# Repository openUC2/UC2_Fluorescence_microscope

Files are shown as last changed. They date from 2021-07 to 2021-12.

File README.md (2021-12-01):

<p align="left">

</p>

# openUC2 Fluorescence Microscope (infinity)
---

This is the repository for the laser-based fluorescence microscope with infinity optics. It is capable to acquire Time-Lapse videos from living cells inside an incubator.

The current version of the Z-stage is inspired by the flexure-bearing Z-stage from Richard Bowman's openflexure microscope design. Their open-source project can be found [here](https://openflexure.org). We also emphasize to use the [delta stage](https://openflexure.org/projects/deltastage/) where [UC2 provides an adapter](https://github.com/openUC2/UC2-GIT/tree/master/CAD/ASSEMBLY_CUBE_Openflexure_Deltastage) for our system.

The setup looks as follows:

<p align="center">
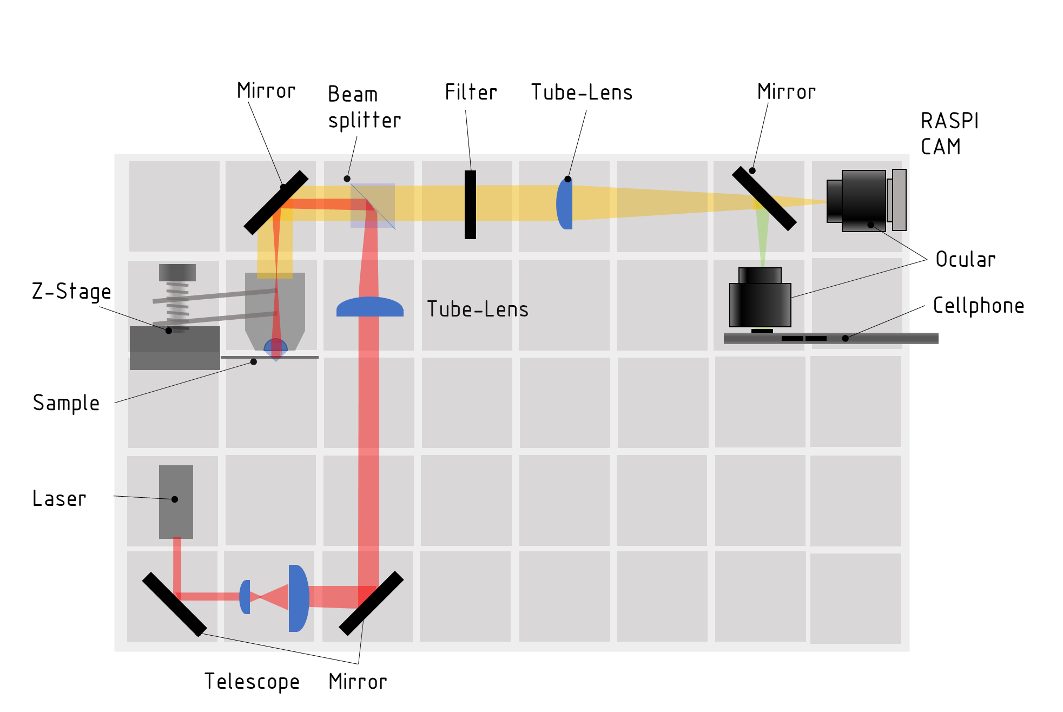
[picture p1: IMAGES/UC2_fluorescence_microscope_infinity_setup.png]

</p>

We use a high power entertainment laser to excite a specific fluorophore, where the emission signal is either filtered by a proper dichroic mirror cube (dichroic+filter) or a low-cost version of a simple 50/50 beamsplitter and an emission filter. The setup uses infinity optics and can either be used with a bare chip or a combination of cellphone camera (with lens) and an eyepiece to achieve proper imaging.

It is a very early developer version. Please feel free to contribute to the documentation and device development.

*Note:* The pictures on this site do not show the latest version of the Z-stage. Follow the respective assembly guidelines.

<p align="center">
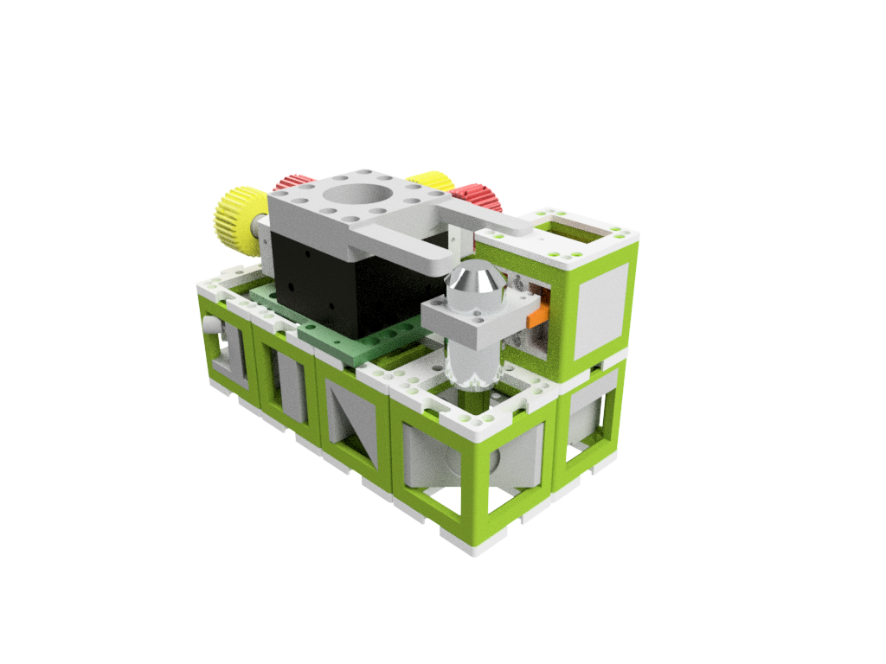
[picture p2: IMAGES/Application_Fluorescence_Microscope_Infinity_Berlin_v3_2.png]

</p>

***Features:***

* X/Y/Z/t Acquisitions possible
* Fluorescent imaging
* Quantitative Phase Imaging
* Modularized design
* Low-cost acquisition
* Based on off-the-shelf components
* Open-Source
* infinity corrected optics
* use of low-cost CMOS sensors possible

# Software
🢂 Find the software for this setup in our dedicated [UC2-Software-GIT](https://github.com/bionanoimaging/UC2-Software-GIT)

# Hardware

Below we describe how the device can be build and assembled in order to replicate the whole system as shown in the rendering above. One needs additional parts that can be found in the core [openUC2 repository](https://github.com/bionanoimaging/UC2-GIT).

### Parts for this setup

<p align="center">
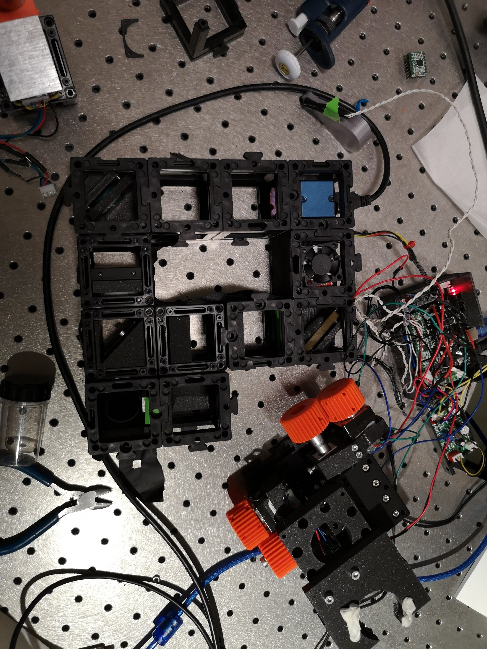
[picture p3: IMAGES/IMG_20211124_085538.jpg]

</p>

| Amount | Type  | Properties | Price | Source |
|----|----|----|----|----|
| 1 | Camera | Daheng Imaging MER2-230-168U3M | 500 € | Daheng Imaging [Link](https://www.machinevisionkamera.de/USB3-Bildverarbeitungskamera-2.3MP-Monochrome-Sony-IMX174-MER2-230-168U3M)|
| 1  | Camera | USB ALVIUM 1800 U -158 | 333 € | Allied Vision [Edmund Optics](https://www.edmundoptics.de/p/allied-vision-alvium-1800-u-158m-129-16mp-s-mount-usb-31-monochrome-camera/42981/) |
| 1 | Laser | 1× Laser Module, 635/637nm entertainment laser (laserlands.net, #3450, Dot Laser Module, 300mW, 50 Euro, China)  | 60 €| [Laserlands.net](https://www.laserlands.net/638nm-laser-500mw-laser-module-red-light-laser.html)|
| 1 | Emission Filter (we used on old Chroma, QE690/55!) | Thorlabs FEL0650 | 78 € | [Thorlabs](https://www.thorlabs.com/thorproduct.cfm?partnumber=FEL0650) |
| 1 | Dichroic Mirror | DMLP650 | 250 € | [Thorlabs](https://www.thorlabs.com/thorproduct.cfm?partnumber=DMLP650) |
| 1 | Shortpass Filter (cleanup)  | FES0650 | 78 € | [Thorlabs](https://www.thorlabs.com/thorproduct.cfm?partnumber=FES0650) |
| 2 | Mirrors 1 inch | Silver, protected mirror | 50 € | [Thorlabs](https://www.thorlabs.com/thorproduct.cfm?partnumber=PF10-03-P01) |
| 1 | Tube lense according to objective lens (imaging-side) | 80 mm for Allied Vision, 150 for Daheng Imaging, Achromat | 96 € | [Thoralbs](https://www.thorlabs.de/thorproduct.cfm?partnumber=AC254-080-A-ML)/[Thoralbs](https://www.thorlabs.de/thorproduct.cfm?partnumber=AC254-150-A-ML) |
| 1 | Tube Lens (illumination-side) | Achromat, f 156,4mm / ∅40,0mm  or  f 150 mm / ∅25,4mm | 5,9 € / 96 € | [PGI-Versand](https://astro-didaktik.de/achromat-2-linser-o-40-mm-f-156-4-mm.html)/[Thoralbs](https://www.thorlabs.de/thorproduct.cfm?partnumber=AC254-150-A-ML) |
| 1 | M3 Screws, DIN ISO 912, various (buy a set) | | ? | Würth |
| 1 | Microscope Objective lens | 1x Objective lens, No Name, 100x, NA1.25, 50 Euro, China | 100 € | [Aliexpress](https://de.aliexpress.com/item/4000200609554.html) |
| 1 | Beam Splitter Dichroic (Discontinued?) | Comar optics Dichro 740 IY als 45° | 40 € | Comar  |
| 1 | Filter Emission (Discontinued?) | Emissionsfilter 655 IY als 0° | 40 € | Comar |
| 200  | Magnets  | 5mm Ball Magnets, NEoxym  | 0,31 | [Magnetmax](https://www.magnetmax.de/Neodym-Kugelmagnete/Magnetkugel-Kugelmagnet-O-5-0-mm-Neodym-vernickelt-N40-haelt-400-g::158.html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) || 4 | Mirrors 1 inch | Thoralbs | ~50 | [Thorlabs](https://www.thorlabs.com/thorproduct.cfm?partnumber=PF10-03-P01) |  1x500 | Screws M3x12 | | ?  | [Würth](https://eshop.wuerth.de/Zylinderschraube-mit-Innensechskant-SHR-ZYL-ISO4762-88-IS25-A2K-M3X12/00843%20%2012.sku/de/DE/EUR/)

Find the complete [Bill-of-Materials here](UC2_Microscope_BillOfMaterial_STORM.xlsx)

## Modules

|  Name | Properties  |  Price | Link  | # |
|---|---|---|---|---|
|  Baseplate puzzle| - | 5€  | [Base-plate](https://github.com/openUC2/UC2-GIT/tree/master/CAD/ASSEMBLY_Baseplate/)  | ~20|
|  Module: Z-Stage | - | ?? €  | [Z-Stage](https://github.com/openUC2/UC2-GIT/tree/master/CAD/ASSEMBLY_CUBE_Z-STAGE_NEMA_MGN)  | 1|
| (Alternative) [Delta stage](https://openflexure.org/projects/deltastage/)  | Openflexure | ?? €  | [Deltastage](https://github.com/openUC2/UC2-GIT/tree/master/CAD/ASSEMBLY_CUBE_Openflexure_Deltastage)  | 1|
|  Module: Kinematic Mirror 45°  (THORLABS!) | - | 5€  | [Kinematic Mirror 45](https://github.com/openUC2/UC2-GIT/tree/master/CAD/ASSEMBLY_CUBE_Mirror_Kinematic_45)  | 2 |
|  Module: Alvium CMOS Camera  | Low-Cost Camera | 5€  | [Alvium Camera](https://github.com/openUC2/UC2-GIT/tree/master/CAD/ASSEMBLY_CUBE_AlliedVision_Alvium)  | 1|
| Alternative (better) Daheng Imaging IMX174 | SMLM Camera | 5€  | [Alvium Camera](https://github.com/openUC2/UC2-GIT/tree/master/CAD/ASSEMBLY_CUBE_AlliedVision_Alvium)  | 1 |
|  Module: Beamsplitter (dichroic)  | - | ??€  | [Dichroic Beam splitter](https://github.com/openUC2/UC2-GIT/tree/master/CAD/ASSEMBLY_CUBE_Dichroic_Beamsplitter)  | 1|
|  Module: Thorlabs + Lens (160mm, 80mm) | - | 5€  | [Thorlabs Insert](https://github.com/openUC2/UC2-GIT/tree/master/CAD/ASSEMBLY_CUBE_Thorlabs)  | 2 |
|  Module: Laser (Block) | - | 5€  | Just mount the laser on the insert using screws. | 2 |
|  Module: 45° Mirror  (Thorlabs) | - | 5€  | [Mirror](https://github.com/openUC2/UC2-GIT/tree/master/CAD/ASSEMBLY_CUBE_Mirror_45)  | 2 |

### Variants

We use various different XY Stages:

[**1. Micrometer XY-stage**](https://github.com/openUC2/UC2-MicronStage)

[**2. Aliexpress Microscop XY-stage**](https://github.com/openUC2/UC2-Motorized-XY-Table)

**3. Openflexure Stage**

### Electronics
🢂 Find more in the [Electronics section](https://github.com/openUC2/UC2-GIT/tree/master/ELECTRONICS)

## Setup variants

**Assembled Setups with a Jetson-driven mono camera:**

For more infos about the camera look [here](https://github.com/openUC2/UC2-GIT/tree/master/CAD/ASSEMBLY_CUBE_AlliedVision_Alvium)

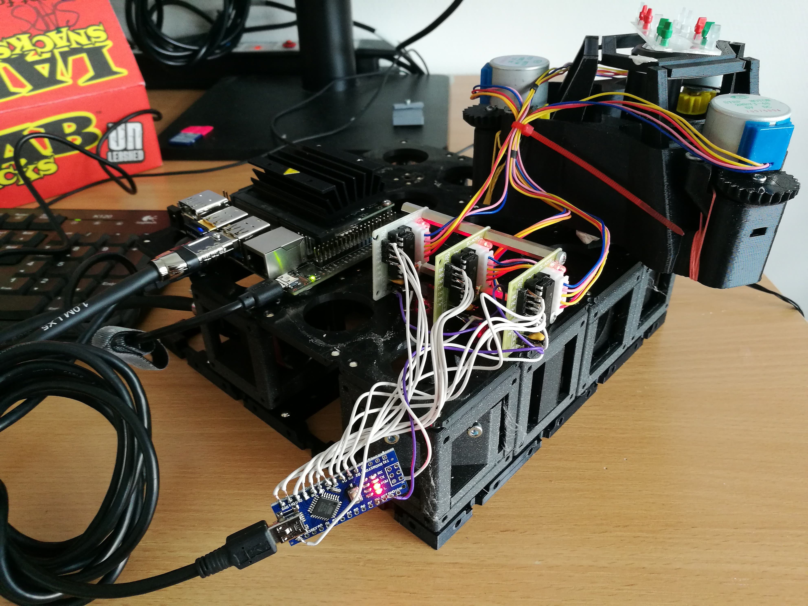
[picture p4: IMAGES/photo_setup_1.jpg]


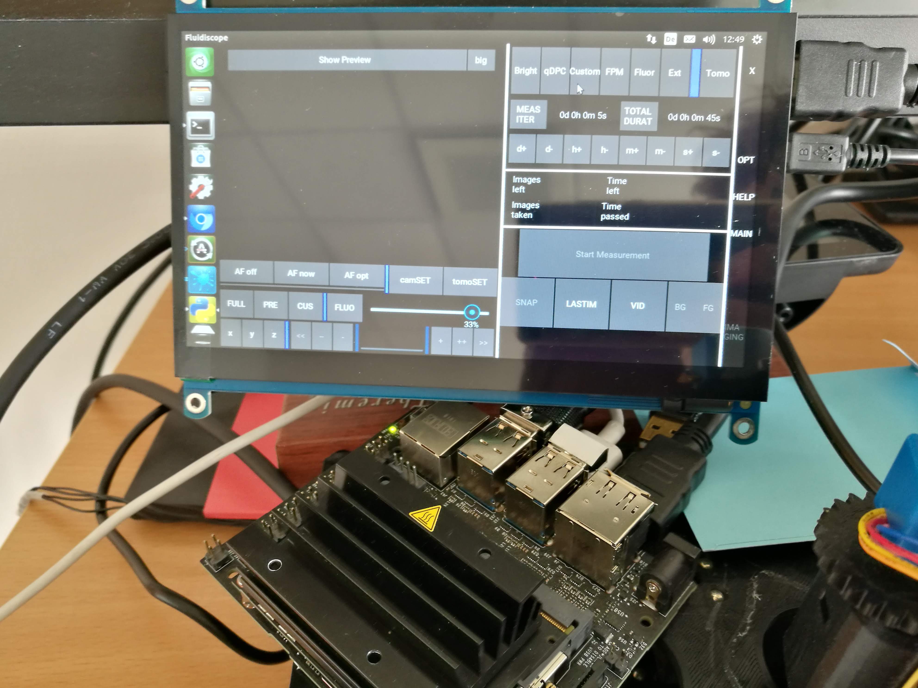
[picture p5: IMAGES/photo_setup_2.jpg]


## Setup

**Side View:**



**Top View:**

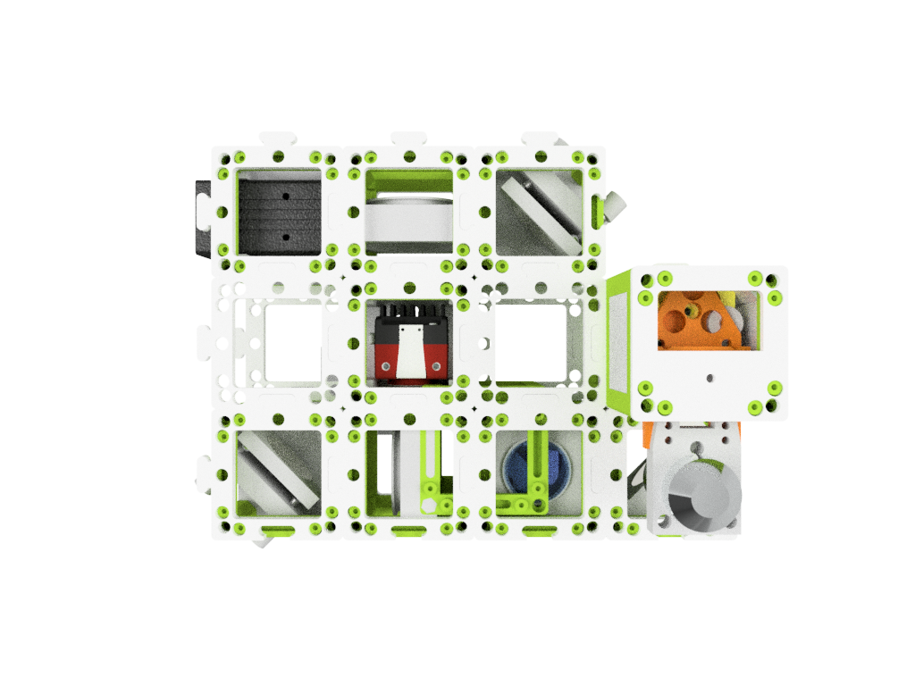
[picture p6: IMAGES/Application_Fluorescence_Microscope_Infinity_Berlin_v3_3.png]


**Backside View:**

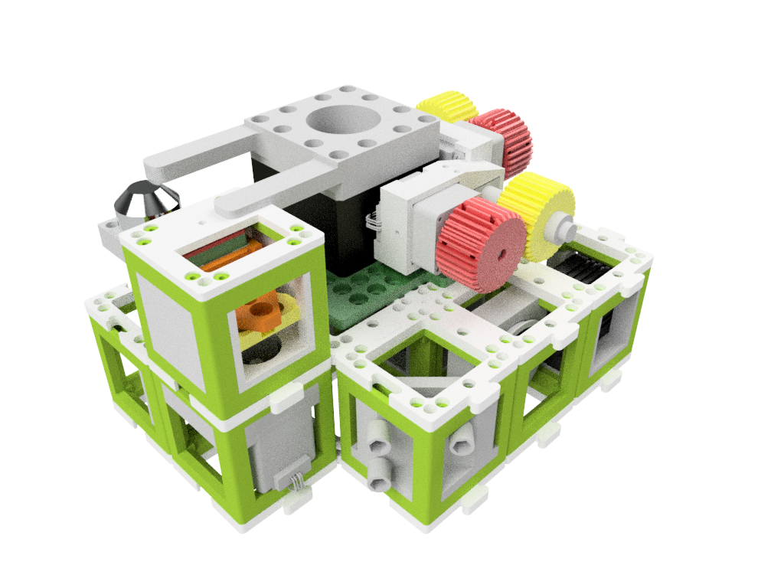
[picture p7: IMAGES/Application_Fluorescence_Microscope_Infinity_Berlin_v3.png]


**Find a little [Tutorial on how to make it work here](Tutorial.md)**

## Showcase
This is a set of ATTO 647 labelled *e.colis* provided by O. Helle from UiO imaged with a 100x, 1.25, a cellphone (Huawei P20 Pro, monochromatic camera, Freedcam) and a 635/637 nm exciation.

<p align="center">
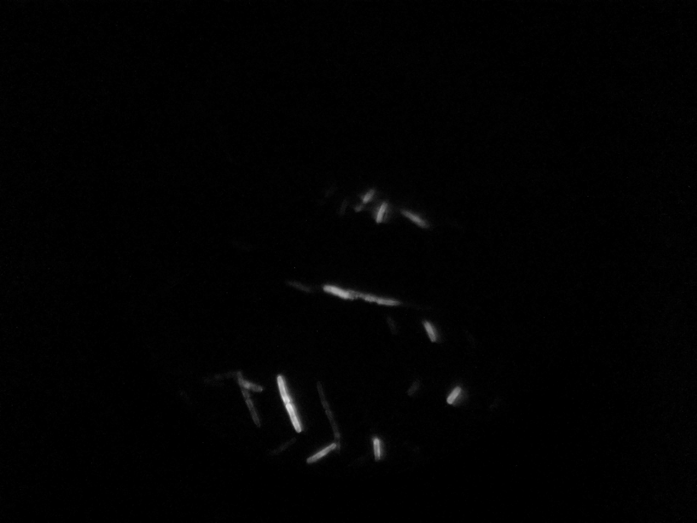
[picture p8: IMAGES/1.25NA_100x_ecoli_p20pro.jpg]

</p>

This is acquired with the Allied Vision Alvium 1500-158 and the new UC2 Nvidia Jetson Nano GUI. HeLa labelled with Alexa Fluor 647 Phal.

***Brightfield***
<p align="center">
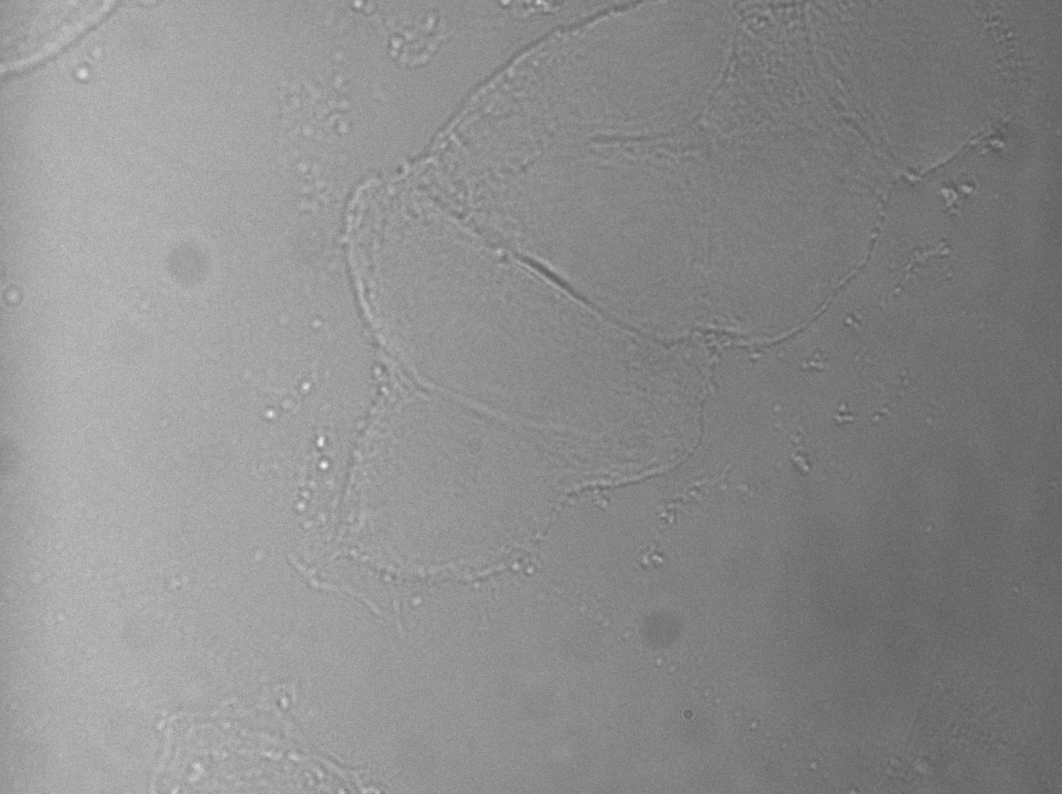
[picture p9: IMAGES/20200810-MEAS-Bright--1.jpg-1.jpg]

</p>

***Fluorescence***
<p align="center">
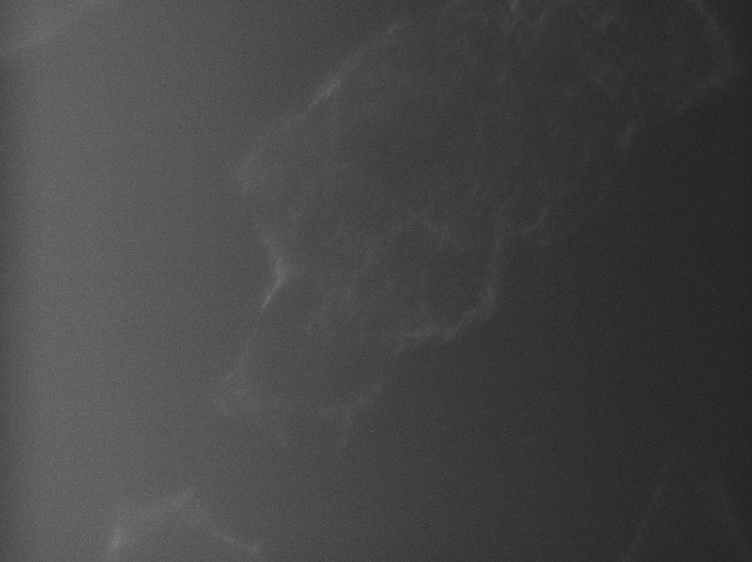
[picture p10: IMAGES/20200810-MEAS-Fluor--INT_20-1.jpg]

</p>

***Overlay***
<p align="center">
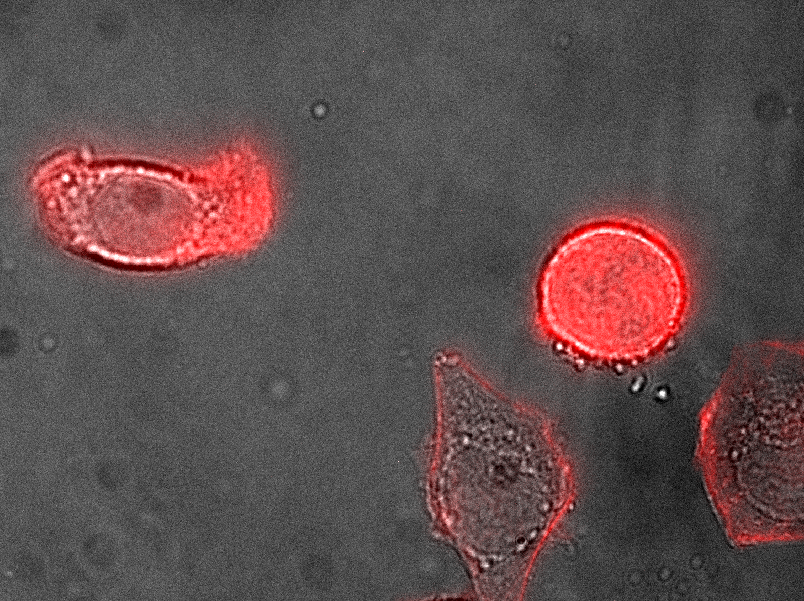
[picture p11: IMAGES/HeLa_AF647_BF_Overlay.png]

</p>

***Optical Setup***
<p align="center">

</p>

***ImSwitch Control Software***
<p align="center">
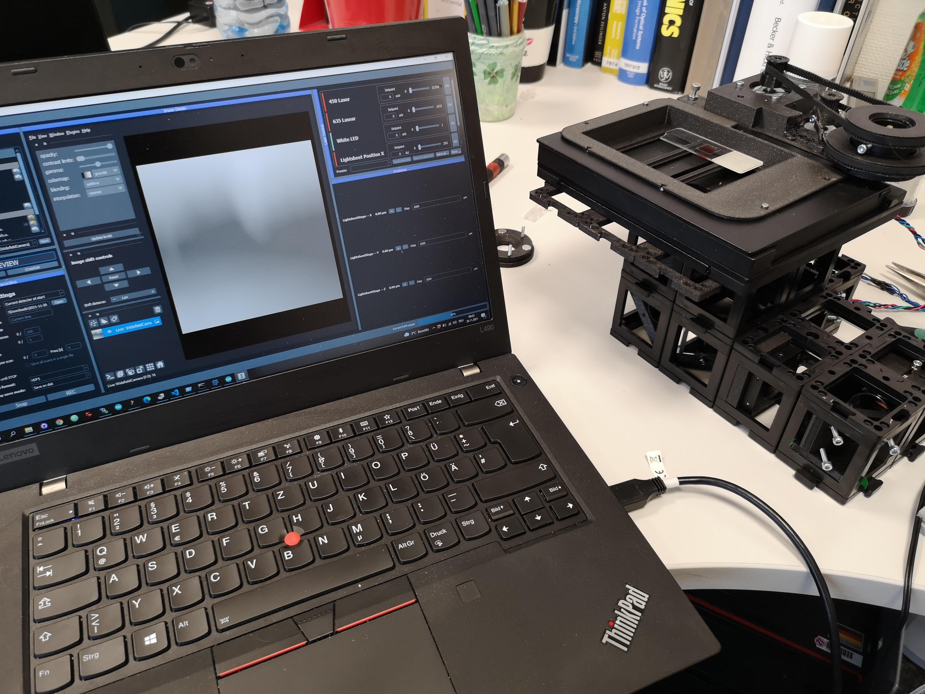
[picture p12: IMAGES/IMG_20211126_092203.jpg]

</p>

***SMLM Sample Holder***
<p align="center">
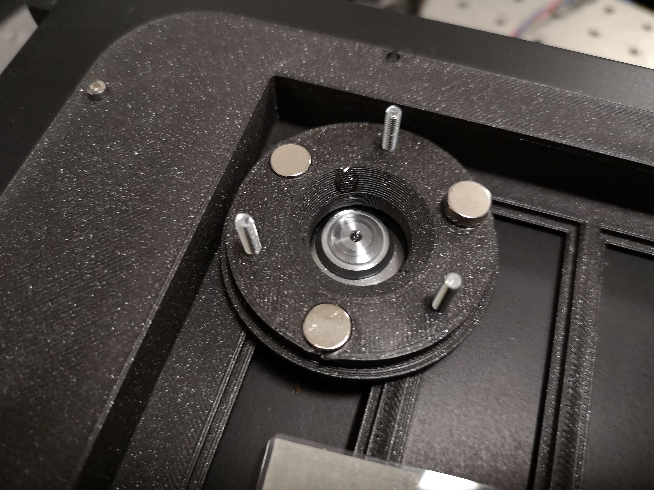
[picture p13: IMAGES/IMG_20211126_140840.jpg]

</p>

## Get Involved

This project is open-source so that anyone can get involved. You don't even have to learn CAD designing or programming. Find ways you can contribute in  [CONTRIBUTING](https://github.com/openUC2/UC2-GIT/blob/master/CONTRIBUTING.md)

## License and Collaboration

This project is open-source and is released under the CERN open hardware license. Our aim is to make the kits commercially available.
We encourage everyone who is using our Toolbox to share their results and ideas, so that the Toolbox keeps improving. It should serve as a easy-to-use and easy-to-access general purpose building block solution for the area of STEAM education. All the design files are generally for free, but we would like to hear from you how is it going.

You're free to fork the project and enhance it. If you have any suggestions to improve it or add any additional functions make a pull-request or file an issue.

Please find the type of licenses [here](https://github.com/openUC2/UC2-GIT/blob/master/License.md)

REMARK: All files have been designed using Autodesk Inventor 2019 (EDUCATION)

## Collaborating
If you find this project useful, please like this repository, follow us on Twitter and cite the webpage! :-)

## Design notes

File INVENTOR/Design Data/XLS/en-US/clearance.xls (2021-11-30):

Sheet: Ansi Unified Screw Threads
I | Sort Order -1
Fastener Type | Size | Shaft Diameters |  |  | Head Dimensions
 |  | Close | Normal | Loose | Diameter | Depth/Angle | Head Type
Flat Head Machine Screw (82) | #0 | 0.0635 | 0.07 | 0.073 | 0.119 | 82 | 2
Flat Head Machine Screw (82) | #1 | 0.076 | 0.081 | 0.089 | 0.146 | 82 | 2
Flat Head Machine Screw (82) | #2 | 0.089 | 0.096 | 0.1065 | 0.172 | 82 | 2
Flat Head Machine Screw (82) | #3 | 0.104 | 0.11 | 0.12 | 0.199 | 82 | 2
Flat Head Machine Screw (82) | #4 | 0.116 | 0.1285 | 0.136 | 0.225 | 82 | 2
Flat Head Machine Screw (82) | #5 | 0.1285 | 0.136 | 0.154 | 0.252 | 82 | 2
Flat Head Machine Screw (82) | #6 | 0.144 | 0.1495 | 0.1695 | 0.279 | 82 | 2
Flat Head Machine Screw (82) | #8 | 0.1695 | 0.177 | 0.1935 | 0.332 | 82 | 2
Flat Head Machine Screw (82) | #10 | 0.196 | 0.201 | 0.221 | 0.385 | 82 | 2
Flat Head Machine Screw (82) | #12 | 0.221 | 0.228 | 0.246 | 0.438 | 82 | 2
Flat Head Machine Screw (82) | 1/4 | 0.257 | 0.266 | 0.2812 | 0.507 | 82 | 2
Flat Head Machine Screw (82) | 5/16 | 0.323 | 0.332 | 0.3437 | 0.635 | 82 | 2
Flat Head Machine Screw (82) | 3/8 | 0.386 | 0.397 | 0.4062 | 0.762 | 82 | 2
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

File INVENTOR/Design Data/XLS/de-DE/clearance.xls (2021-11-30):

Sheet: ANSI UST
I | Reihenfolge -1
Schraubentyp | Größe | Wellendurchmesser |  |  | Schraubenkopfbemaßungen
 |  | Schließen | Normal | Grob | Durchmesser | Tiefe/Winkel | Schraubenkopftyp
Flachkopfmaschinenschraube (82) | #0 | 0.0635 | 0.07 | 0.073 | 0.119 | 82 | 2
Flachkopfmaschinenschraube (82) | #1 | 0.076 | 0.081 | 0.089 | 0.146 | 82 | 2
Flachkopfmaschinenschraube (82) | #2 | 0.089 | 0.096 | 0.1065 | 0.172 | 82 | 2
Flachkopfmaschinenschraube (82) | #3 | 0.104 | 0.11 | 0.12 | 0.199 | 82 | 2
Flachkopfmaschinenschraube (82) | #4 | 0.116 | 0.1285 | 0.136 | 0.225 | 82 | 2
Flachkopfmaschinenschraube (82) | #5 | 0.1285 | 0.136 | 0.154 | 0.252 | 82 | 2
Flachkopfmaschinenschraube (82) | #6 | 0.144 | 0.1495 | 0.1695 | 0.279 | 82 | 2
Flachkopfmaschinenschraube (82) | #8 | 0.1695 | 0.177 | 0.1935 | 0.332 | 82 | 2
Flachkopfmaschinenschraube (82) | #10 | 0.196 | 0.201 | 0.221 | 0.385 | 82 | 2
Flachkopfmaschinenschraube (82) | #12 | 0.221 | 0.228 | 0.246 | 0.438 | 82 | 2
Flachkopfmaschinenschraube (82) | 1/4 | 0.257 | 0.266 | 0.2812 | 0.507 | 82 | 2
Flachkopfmaschinenschraube (82) | 5/16 | 0.323 | 0.332 | 0.3437 | 0.635 | 82 | 2
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

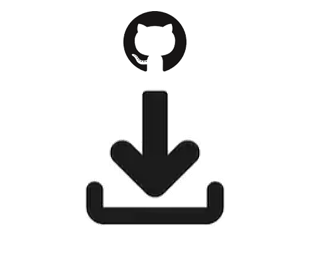
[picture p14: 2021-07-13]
IMAGES/D.png

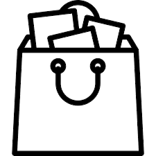
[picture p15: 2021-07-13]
IMAGES/B.png

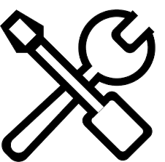
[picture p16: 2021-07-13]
IMAGES/A.png

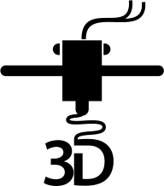
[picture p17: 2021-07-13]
IMAGES/P.png

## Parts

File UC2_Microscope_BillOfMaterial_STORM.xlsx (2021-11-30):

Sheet: NEW
Rough Price for one high-throughput microscope (without Laptop)
Shop | Name | URL | Amount | Price | Final Price
Robotershop | MGN12H Linearlager | https://www.roboter-bausatz.de/p/mgn12h-linearlager | 2 | 10 | 20
 | Linearführung MGN12H 450mm, 50mm (https://www.roboter-bausatz.de/p/linearfuehrung-mgn12h-450mm) | https://www.roboter-bausatz.de/p/mgn12h-linearlager?sPartner=8 | 1 | 30 | 30
 | 1× MKS DLC CNC / Lasergravierer Mainboard GRBL24,95 €* (https://www.roboter-bausatz.de/p/mks-dlc-cnc-lasergravierer-mainboard-grbl) |  | 1 | 12.475 | 12.475
 | 4× A4988 Schrittmotorentreiber5,00 €* (https://www.roboter-bausatz.de/p/a4988-schrittmotorentreiber) |  | 4 | 2.5 | 10
 | 1× yourDroid Netzteil 12V 3A 5,5x2,1mm DC-Stecker9,95 €* (https://www.roboter-bausatz.de/p/yourdroid-netzteil-12v-3a-5-5x2-1mm-dc-stecker) |  | 1 | 4.975 | 4.975
 | 4x jumper kabel 4x |  | 4 | 1 | 4
 | 1× 50 MicroSchalter / Drucktaster 6x6x6mm0,85 €* (https://www.roboter-bausatz.de/p/50-microschalter-drucktaster-6x6x6mm) |  | 1 | 0.425 | 0.425
 | 1× 2 Pin Dupont / Jumper Kabel Buchse-Buchse 70 cm0,45 €* (https://www.roboter-bausatz.de/p/2-pin-dupont-jumper-kabel-buchse-buchse-70-cm) |  | 1 | 0.225 | 0.225
Aliexpress | Twotrees CNC TT-5,5 Laser Gravur Maschine | https://de.aliexpress.com/item/4000033085016.html?spm=a2g0s.9042311.0.0.211d4c4dKo5Nbn | 1 | 129 | 129
Edmund Optics | Allied Vision Alvium USB 3.1 Kamera 1800 U-158m, 1/2,9", 1,58 MP, C-Mount, monochrom (https://www.edmundoptics.de/p/allied-vision-alvium-1800-u-158m-129-158mp-c-mount-usb-31-monochrome-camera/44757/) |  | 1 | 330 | 330
 | 25,4 mm Durchm., Enhanced Aluminium, 4-6 λ Oberflächenspiegel (https://www.edmundoptics.de/p/254mm-dia-enhanced-aluminum-4-6lambda-mirror/26562/) |  | 3 | 21 | 63
 | 6mm Durchmesser x 30mm Länge, M3 Gewinde, Cage-System Stange (https://www.edmundoptics.de/p/6mm-diameter-x-30mm-length-m3-cage-support-rod/28337/) |  | 2 | 11.5 | 23
 | 25,4 mm D. x 88,9 mm Brennweite, VIS 0°-beschichtet, Achromat (https://www.edmundoptics.de/p/254mm-dia-x-889mm-fl-vis-0deg-coated-achromatic-lens/10243/) |  | 1 | 96 | 96
 | 550nm, 25mm Diameter, Dichroic Longpass Filter | https://www.edmundoptics.com/p/550nm-25mm-diameter-dichroic-longpass-filter/24155/ | 0 | 121.125 | 0
 | 500nm, 25mm Diameter, Dichroic Longpass Filter | https://www.edmundoptics.com/p/500nm-25mm-diameter-dichroic-longpass-filter/24154/ | 0 | 121.125 | 0
 | 650nm, 25mm Diameter, Dichroic Longpass Filter | https://www.edmundoptics.com/p/650nm-25mm-diameter-dichroic-longpass-filter/24157/ | 1 | 121.125 | 121.125
 | 500nm, 25mm Dia., OD 2.0 Longpass Filter | https://www.edmundoptics.com/p/500nm-25mm-dia-od-20-longpass-filter/43525/ | 0 | 80.75 | 0
 | 550nm, 25mm Dia., OD 2.0 Longpass Filter | https://www.edmundoptics.com/p/550nm-25mm-dia-od-20-longpass-filter/43526/ | 0 | 80.75 | 0
 | 650nm, 25mm Dia., OD 2.0 Longpass Filter | https://www.edmundoptics.com/p/650nm-25mm-dia-od-20-longpass-filter/43528/ | 1 | 80.75 | 80.75
Optik-Pro | Optika Objektiv IOS LWD W-PLAN POL objective 20x/0.40, M-1138 |  | 0 | 168 | 0
 | Euromex Objektiv IS.7220, 20x/0.40, PLi, plan, infinity (iScope) | https://www.optik-pro.de/fuer-mikroskope/optika-objektiv-ios-lwd-w-plan-pol-objective-20x-0-40-m-1138/p,66005 | 0 | 159 | 0
 | Motic Objektiv CCIS plan achromat. EC-H PL 20x/0.45 (AA=0.9mm) | https://www.optik-pro.de/fuer-mikroskope/euromex-objektiv-is-7220-20x-0-40-pli-plan-infinity-iscope-/p,53372 | 0 | 169 | 0
 | Motic Objektiv EC PL, CCIS, plan, achro, NGC 20x/0.45 w.d. 1mm (BA-310 Elite) | https://www.optik-pro.de/fuer-mikroskope/motic-objektiv-ccis-plan-achromat-ec-h-pl-20x-0-45-aa-0-9mm-/p,45909 | 1 | 113 | 113
 | Windaus Objektiv 10x für HPM 100er Modelle | https://www.optik-pro.de/fuer-mikroskope/motic-objektiv-ec-pl-ccis-plan-achro-ngc-20x-0-45-w-d-1mm-ba-310-elite-/p,57139 | 1 | 32 | 32
 |  | https://www.optik-pro.de/fuer-mikroskope/windaus-objektiv-10x-fuer-hpm-100er-modelle/p,7108 |  |  | 0
 |  |  |  |  | 0
Prusa | Original Prusa Prusament PETG Galaxie Schwarz 1,75 mm 1.000 g |  | 1 | 30 | 30
 |  | https://www.igo3d.com/original-prusa-prusament-petg-filament_8 |  |  | 0
Laserlands.net | 638nm Red Laser Module 500mW Round Dot Focusable TTL 3050 | https://www.laserlands.net/638nm-red-laser-module-500mw-round-dot-focusable-ttl-3050.html | 1 | 25.5 | 25.5
 | 3050-488D-60-12VDC Laserland 488nm Cyan Semiconductor Laser Module 60mW Laser Head Lighting Effect 487nm | https://www.laserlands.net/laserland-488nm-cyan-semiconductor-laser-module-60mw-laser-head-lighting-effect-487nm.html | 0 | 67.1415 | 0
 | 4060 530nm 200mw Green Diode Laser Module | https://www.laserlands.net/11051018.html | 0 | 32.3 | 0
 |  |  |  |  | 0
 |  |  |  |  | 0
Thorlabs | F6SS088- ( Gesamtgewicht):0.01 Kgs, Fine Hex Adjuster, 6-80, 0.88" Long |  | 3 | 7.54 € | 22.62
 | F6SSN1P- ( Gesamtgewicht):0.01 Kgs, Threaded Bushing, Phosphor Bronze, 6-80, 0.25" Long |  | 3 | 4.82 € | 14.46
Misc | Screws |  | 1 | 25 | 25
 | LED (Brightfield) |  | 1 | 20 | 20
UC2 | 45° Mirror |  | 1
 | 45° mirror, kinematic |  | 2
 | Camera |  | 1
 | Filtercube |  | 1
 |  |  | 1
 | Empty |  | 12
 | Cubes total |  | 18 | 15 | 270
 | Baseplates |  | 36 | 10 | 360
 | Working Hours? |  | 8 | 50 | 400
 | Missing Things |  | 1 | 200 | 200
Eckstein | Pololu Stepper Motor NEMA 11 Bipolar 200 Steps Rev 28×32mm 3.8V 0.67 A Phase | https://eckstein-shop.de/PololuStepperMotorNEMA11Bipolar200StepsRev28C39732mm38V067APhase | 1 | 22.95 | 22.95
 |  |  |  | TOTAL: | 2460.505
STORM
Amount | Type | Properties | Price | Source
1 | Camera | Daheng Imaging MER2-230-168U3M | 500 | Daheng Imaging (https://www.alliedvision.com/de/produkte/embedded-vision-kameras/detail/Alvium%201800%20U/-158.html)
1 | Camera | USB ALVIUM 1800 U -158 | 250 | Allied Vision (https://www.alliedvision.com/de/produkte/embedded-vision-kameras/detail/Alvium%201800%20U/-158.html)
1 | Laser | 1× Laser Module, 635/637nm entertainment laser (laserlands.net, #3450, Dot Laser Module, 300mW, 50 Euro, China) (https://www.laserlands.net/diode-laser-module/600nm-640nm-orange-red-laser-module/635dot/200mw-300mw-637nm-638nm-laser-diode-module-ttl-stage-lighting-dj-show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) | 50 | Laserlands.net (https://www.laserlands.net/diode-laser-module/600nm-640nm-orange-red-laser-module/635dot/200mw-300mw-637nm-638nm-laser-diode-module-ttl-stage-lighting-dj-show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)
1 | Beam Splitter Dichroic | Comar optics Dichro 740 IY als 45 | 40 | Comar (https://www.comaroptics.com/components/filters/dichroic-filters/long-pass-dichroic-filters)
1 | Filter Emission | Emissionsfilter 655 IY als 0° | 40 | Comar (https://www.comaroptics.com/components/filters/dichroic-filters/long-pass-dichroic-filters)
1 | Emission Filter | Thorlabs FEL0650 | 78 | Thorlabs
1 | Dichroic Mirror | , DMLP650 | 250 | Thorlabs
1 | Shortpass Filter (cleanup) | FES0650 | 78 | Thorlabs
2 | Mirrors 1 inch | Silver, protected mirror | ~50 | Thorlabs (https://www.thorlabs.com/thorproduct.cfm?partnumber=PF10-03-P01)
1 | Tube lense according to objective lens | 80 mm for Allied Vision, 160 for Daheng Imaging, Achromat | 80 | Thoralbs
1 | Tube Lens | Achromat, f 156,4mm / ∅ 40,0mm | 5.9 | PGI-Versand (https://www.pgi-versand.de/?id=47&mode=artdet&artnr=563.OA.63)
1 | Tube Lens alternative | Achromat, f 182,8mm / ∅ 50,0mm | 7.9 | PGI-Versand (https://www.pgi-versand.de/?id=47&mode=artdet&artnr=564.OA.64)
1 | M3 Screws |  | ? | Würth (https://eshop.wuerth.de/Zylinderschraube-mit-Innensechskant-SHR-ZYL-ISO4762-88-IS25-A2K-M3X12/00843%20%2012.sku/de/DE/EUR/)
1 | Microscope Objective lens | 1x Objective lens, No Name, 100x, NA1.25, 50 Euro, China 🢂 (https://de.aliexpress.com/item/664303199.html) | 100 | https://de.aliexpress.com/item/4000200609554.html

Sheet: OLD
Rough Price for one high-throughput microscope (without Laptop)
Shop | Name | URL | Amount | Price | Final Price
Robotershop | 4× 0,5 Meter Aluprofil 20x20 I-Typ Nut 59,40 €* (https://www.roboter-bausatz.de/p/0-5-meter-aluprofil-20x20-i-typ-nut-5) |  | 4 | 4.7 | 18.8
 | GT2 Riemenscheibe 20 Zähne 5mm Bohrung für 6mm Riemen | https://www.roboter-bausatz.de/p/gt2-riemenscheibe-20-zaehne-5mm-bohrung-fuer-6mm-riemen | 2 | 1.25 | 2.5
 | Nutenstein glatt I-Typ Nut 5 [M4] | https://www.roboter-bausatz.de/p/nutenstein-glatt-i-typ-nut-5-m4 | 10 | 0.6 | 6
 | 2× Wantai Nema 17 Schrittmotor 40mm 1.7A 42BYGHW609X126,90 €* (https://www.roboter-bausatz.de/p/nema-17-schrittmotor-48mm) |  | 2 | 4.7 | 9.4
 | 1× 10 Meter GT2 Zahnriemen offen 6mm10,40 €* (https://www.roboter-bausatz.de/p/10-meter-gt2-zahnriemen-offen-6mm) |  | 1 | 5.2 | 5.2
 | 2× Riemenscheibe GT2 20 Zähne 8mm Bohrung für 6mm Riemen2,90 €* (https://www.roboter-bausatz.de/p/riemenscheibe-gt2-20-zaehne-8mm-bohrung-fuer-6mm-riemen) |  | 2 | 1.45 | 2.9
 | V-Slot Führungsrolle mit Kugellager (klein) | https://www.roboter-bausatz.de/p/v-slot-fuehrungsrolle-mit-kugellager-klein | 6 | 1.25 | 7.5
 | 1× MKS DLC CNC / Lasergravierer Mainboard GRBL24,95 €* (https://www.roboter-bausatz.de/p/mks-dlc-cnc-lasergravierer-mainboard-grbl) |  | 1 | 12.475 | 12.475
 | 4× A4988 Schrittmotorentreiber5,00 €* (https://www.roboter-bausatz.de/p/a4988-schrittmotorentreiber) |  | 4 | 2.5 | 10
 | 1× yourDroid Netzteil 12V 3A 5,5x2,1mm DC-Stecker9,95 €* (https://www.roboter-bausatz.de/p/yourdroid-netzteil-12v-3a-5-5x2-1mm-dc-stecker) |  | 1 | 4.975 | 4.975
 |  |  |  | 0.5 | 0
 | 1× 50 MicroSchalter / Drucktaster 6x6x6mm0,85 €* (https://www.roboter-bausatz.de/p/50-microschalter-drucktaster-6x6x6mm) |  | 1 | 0.425 | 0.425
 | 1× 2 Pin Dupont / Jumper Kabel Buchse-Buchse 70 cm0,45 €* (https://www.roboter-bausatz.de/p/2-pin-dupont-jumper-kabel-buchse-buchse-70-cm) |  | 1 | 0.225 | 0.225
 | 1× 10er Set Befestigungsschrauben Winkel 30 I-Typ DIN 7380 M6x121,86 €* (https://www.roboter-bausatz.de/p/10er-set-befestigungsschrauben-winkel-30-i-typ-din-7380-m6x12) |  | 1 | 0.93 | 0.93
 | MGN12H Linearlager | https://www.roboter-bausatz.de/p/mgn12h-linearlager | 1 | 10 | 10
 | Linearführung MGN12H 450mm, 50mm (https://www.roboter-bausatz.de/p/linearfuehrung-mgn12h-450mm) | https://www.roboter-bausatz.de/p/mgn12h-linearlager?sPartner=8 | 1 | 30 | 30
Edmund Optics | Allied Vision Alvium USB 3.1 Kamera 1800 U-158m, 1/2,9", 1,58 MP, C-Mount, monochrom (https://www.edmundoptics.de/p/allied-vision-alvium-1800-u-158m-129-158mp-c-mount-usb-31-monochrome-camera/44757/) | https://www.roboter-bausatz.de/p/linearfuehrung-mgn12h-450mm | 1 | 330 | 330
 | 25,4 mm Durchm., Enhanced Aluminium, 4-6 λ Oberflächenspiegel (https://www.edmundoptics.de/p/254mm-dia-enhanced-aluminum-4-6lambda-mirror/26562/) |  | 3 | 21 | 63
 | 6mm Durchmesser x 30mm Länge, M3 Gewinde, Cage-System Stange (https://www.edmundoptics.de/p/6mm-diameter-x-30mm-length-m3-cage-support-rod/28337/) |  | 4 | 11.5 | 46
 | 25,4 mm D. x 88,9 mm Brennweite, VIS 0°-beschichtet, Achromat (https://www.edmundoptics.de/p/254mm-dia-x-889mm-fl-vis-0deg-coated-achromatic-lens/10243/) |  | 1 | 96 | 96
 | 550nm, 25mm Diameter, Dichroic Longpass Filter | https://www.edmundoptics.com/p/550nm-25mm-diameter-dichroic-longpass-filter/24155/ | 1 | 121.125 | 121.125
 | 500nm, 25mm Diameter, Dichroic Longpass Filter | https://www.edmundoptics.com/p/500nm-25mm-diameter-dichroic-longpass-filter/24154/ | 1 | 121.125 | 121.125
 | 650nm, 25mm Diameter, Dichroic Longpass Filter | https://www.edmundoptics.com/p/650nm-25mm-diameter-dichroic-longpass-filter/24157/ | 1 | 121.125 | 121.125
 | 500nm, 25mm Dia., OD 2.0 Longpass Filter | https://www.edmundoptics.com/p/500nm-25mm-dia-od-20-longpass-filter/43525/ | 1 | 80.75 | 80.75
 | 550nm, 25mm Dia., OD 2.0 Longpass Filter | https://www.edmundoptics.com/p/550nm-25mm-dia-od-20-longpass-filter/43526/ | 1 | 80.75 | 80.75
 | 650nm, 25mm Dia., OD 2.0 Longpass Filter | https://www.edmundoptics.com/p/650nm-25mm-dia-od-20-longpass-filter/43528/ | 1 | 80.75 | 80.75
Optik-Pro | Optika Objektiv IOS LWD W-PLAN POL objective 20x/0.40, M-1138 |  | 0 | 168 | 0
 | Euromex Objektiv IS.7220, 20x/0.40, PLi, plan, infinity (iScope) | https://www.optik-pro.de/fuer-mikroskope/optika-objektiv-ios-lwd-w-plan-pol-objective-20x-0-40-m-1138/p,66005 | 0 | 159 | 0
 | Motic Objektiv CCIS plan achromat. EC-H PL 20x/0.45 (AA=0.9mm) | https://www.optik-pro.de/fuer-mikroskope/euromex-objektiv-is-7220-20x-0-40-pli-plan-infinity-iscope-/p,53372 | 0 | 169 | 0
 | Motic Objektiv EC PL, CCIS, plan, achro, NGC 20x/0.45 w.d. 1mm (BA-310 Elite) | https://www.optik-pro.de/fuer-mikroskope/motic-objektiv-ccis-plan-achromat-ec-h-pl-20x-0-45-aa-0-9mm-/p,45909 | 1 | 113 | 113
 | Windaus Objektiv 10x für HPM 100er Modelle | https://www.optik-pro.de/fuer-mikroskope/motic-objektiv-ec-pl-ccis-plan-achro-ngc-20x-0-45-w-d-1mm-ba-310-elite-/p,57139 | 1 | 32 | 32
 |  | https://www.optik-pro.de/fuer-mikroskope/windaus-objektiv-10x-fuer-hpm-100er-modelle/p,7108 |  |  | 0
 |  |  |  |  | 0
Prusa | Original Prusa Prusament PETG Galaxie Schwarz 1,75 mm 1.000 g |  | 1 | 30 | 30
 |  | https://www.igo3d.com/original-prusa-prusament-petg-filament_8 |  |  | 0
Laserlands.net | 638nm Red Laser Module 500mW Round Dot Focusable TTL 3050 | https://www.laserlands.net/638nm-red-laser-module-500mw-round-dot-focusable-ttl-3050.html | 1 | 25.5 | 25.5
 | 3050-488D-60-12VDC Laserland 488nm Cyan Semiconductor Laser Module 60mW Laser Head Lighting Effect 487nm | https://www.laserlands.net/laserland-488nm-cyan-semiconductor-laser-module-60mw-laser-head-lighting-effect-487nm.html | 1 | 67.1415 | 67.1415
 | 4060 530nm 200mw Green Diode Laser Module | https://www.laserlands.net/11051018.html | 1 | 32.3 | 32.3
 |  |  |  |  | 0
 |  |  |  |  | 0
Thorlabs | F6SS088- ( Gesamtgewicht):0.01 Kgs, Fine Hex Adjuster, 6-80, 0.88" Long |  | 3 | 7.54 € | 22.62
 | F6SSN1P- ( Gesamtgewicht):0.01 Kgs, Threaded Bushing, Phosphor Bronze, 6-80, 0.25" Long |  | 3 | 4.82 € | 14.46
Misc | Screws |  | 1 | 25 | 25
 | LED (Brightfield) |  | 1 | 20 | 20
UC2 | 45° Mirror |  | 1
 | 45° mirror, kinematic |  | 2
 | Camera |  | 1
 | Filtercube |  | 1
 |  |  | 1
 | Empty |  | 12
 | Cubes total |  | 18 | 15 | 270
 | Baseplates |  | 36 | 10 | 360
 | Working Hours? |  | 10 | 50 | 500
 | Missing Things |  | 1 | 200 | 200
Reichelt
 | MS20 B20X40X50 (https://www.reichelt.de/profil-20-MS20%20B20X40X50) | https://www.reichelt.de/profil-20-offen-b-20-x-40-50-cm-ms20-b20x40x50-p167124.html?&nbc=1 | 1 | 3.7 | 3.7
 | MS20 B20X20X50 | https://www.reichelt.de/profil-20-offen-b-20-x-20-50-cm-ms20-b20x20x50-p167118.html?&nbc=1 | 1 | 7 | 7
 | DEBO JT ESP32 | https://www.reichelt.de/nodemcu-esp32-wifi-und-bluetooth-modul-debo-jt-esp32-p219897.html?&nbc=1 | 2 | 11.5 | 23
Eckstein | Pololu Stepper Motor NEMA 11 Bipolar 200 Steps Rev 28×32mm 3.8V 0.67 A Phase | https://eckstein-shop.de/PololuStepperMotorNEMA11Bipolar200StepsRev28C39732mm38V067APhase | 1 | 22.95 | 22.95
 |  |  |  | TOTAL: | 3030.6265

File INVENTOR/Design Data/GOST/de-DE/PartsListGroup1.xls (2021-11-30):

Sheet: Лист 1
Инв. № подл |  |  |  | Подп. и дата | Взам. инв. № | Инв. № дубл. |  |  | Подп. и дата
Формат | Зона | Поз. | Обозначение |  |  |  | Наименование |  |  |  |  |  | Кол. на исполнение
 |  |  |  |  |  |  |  |  |  |  |  | Лит.
 |  |  |  |  |  |  |  |  |  |  |  | Код
 |  |  |  |  |  |  |  | Изм. | Лист | № докум | Подпись |  | Дата
 |  |  |  |  |  |  |  | Разраб.
 |  |  |  |  |  |  |  | Пров.
 |  |  |  |  |  |  |  | Н.контр
 |  |  |  |  |  |  |  | Утв.
 |  |  |  |  |  |  |  |  |  |  |  |  |  | Копировал

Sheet: Лист 2
Инв. № подл |  |  |  | Подп. и дата | Взам. инв. № | Инв. № дубл. |  |  | Подп. и дата
Формат | Зона | Поз. | Обозначение |  |  |  | Наименование |  |  |  |  | Кол. на исполнение
 |  |  |  |  |  |  |  | Изм. | Лист | № докум. | Подп. | Дата
 |  |  |  |  |  |  |  |  |  |  |  |  | Копировал
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

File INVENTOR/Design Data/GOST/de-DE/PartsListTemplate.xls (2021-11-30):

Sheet: Лист 1
 | Формат | Зона |  | Поз. |  | Обозначение |  |  |  | Наименование |  |  |  | Кол. | Приме-чание
Подп. и дата
Инв. № дубл.
Взам. инв. №
Подп. и дата
 | Изм. |  | Лист |  | № докум |  | Подпись | Дата
Инв. № подл | Разраб. |  |  |  |  |  |  |  |  |  | Литера |  | Лист |  |  | Листов
 | Пров.
 | Н.контр
 | Утв.
 |  |  |  |  |  |  |  |  | Копировал |  |  | Формат А4

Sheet: Лист 2
 | Формат | Зона |  | Поз. |  | Обозначение |  |  |  | Наименование |  | Кол. | Приме-чание
Подп. и дата
Инв. № дубл.
Взам. инв. №
Подп. и дата
Инв. № подл
 | Изм. |  | Лист |  | № докум. |  | Подп. |  | Дата
 |  |  |  |  |  |  |  | Копировал |  |  | Формат А4
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

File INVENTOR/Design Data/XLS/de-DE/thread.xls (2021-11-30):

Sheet: Inch Tapping Threads
I Q X | Zoll-Blechschraubgewinde |  | Sort Order - 5 |  | External |  |  |  |  |  |  | Internal
 |  |  |  |  |  | Major Dia |  | Pitch Dia |  | Minor Dia |  |  | Minor Dia |  | Pitch Dia |  | Major Dia |  | Tap Drill
Size | Size Suffix | Thread Designation | Custom Thread Designation | TPI | Class | Max | Min | Max | Min | Max | Min | Class | Min | Max | Min | Max | Min | Max | Basic
0.0600 |  | 0-48 | 0-48 | 48 | 2B | 0.0600 | 0.0540 | 0.0480 | 0.0435 | 0.0360 | 0.0330
0.0730 |  | 1-42 | 1-42 | 42 | 2B | 0.0750 | 0.0690 | 0.0620 | 0.0575 | 0.0490 | 0.0460
0.0860 |  | 2-32 | 2-32 | 32 | 2B | 0.0880 | 0.0820 | 0.0760 | 0.0710 | 0.0640 | 0.0600
0.0990 |  | 3-28 | 3-28 | 28 | 2B | 0.1010 | 0.0950 | 0.0880 | 0.0830 | 0.0750 | 0.0710
0.1120 |  | 4-24 | 4-24 | 24 | 2B | 0.1140 | 0.1080 | 0.1000 | 0.0950 | 0.0860 | 0.0820
0.1250 |  | 5-20 | 5-20 | 20 | 2B | 0.1300 | 0.1230 | 0.1120 | 0.1065 | 0.0940 | 0.0900
0.1380 |  | 6-20 | 6-20 | 20 | 2B | 0.1390 | 0.1320 | 0.1215 | 0.1155 | 0.1040 | 0.0990
0.1510 |  | 7-19 | 7-19 | 19 | 2B | 0.1540 | 0.1470 | 0.1345 | 0.1280 | 0.1150 | 0.1090
0.1640 |  | 8-18 | 8-18 | 18 | 2B | 0.1660 | 0.1590 | 0.1440 | 0.1375 | 0.1220 | 0.1160
0.1900 |  | 10-16 | 10-16 | 16 | 2B | 0.1890 | 0.1820 | 0.1650 | 0.1585 | 0.1410 | 0.1350
0.2160 |  | 12-14 | 12-14 | 14 | 2B | 0.2150 | 0.2080 | 0.1895 | 0.1825 | 0.1640 | 0.1570
0.2420 |  | 14-14 | 14-14 | 14 | 2B | 0.2410 | 0.2340 | 0.2130 | 0.2060 | 0.1850 | 0.1780
0.2500 |  | 1/4-14 | 1/4-14 | 14 | 2B | 0.2460 | 0.2370 | 0.2190 | 0.2110 | 0.1920 | 0.1850
0.3125 |  | 5/16-12 | 5/16-12 | 12 | 2B | 0.3150 | 0.3060 | 0.2795 | 0.2710 | 0.2440 | 0.2360
0.3750 |  | 3/8-12 | 3/8-12 | 12 | 2B | 0.3800 | 0.3710 | 0.3445 | 0.3350 | 0.3090 | 0.2990
0.4375 |  | 7/16-10 | 7/16-10 | 10 | 2B | 0.4400 | 0.4290 | 0.3995 | 0.3890 | 0.3590 | 0.3490
0.5000 |  | 1/2-10 | 1/2-10 | 10 | 2B | 0.5040 | 0.4930 | 0.4635 | 0.4530 | 0.4230 | 0.4130

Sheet: Metric Forming Screw Threads
M P X | Metrisch geform. Schraubgewinde |  | Sort Order - 6 |  | External |  |  |  |  |  |  | Internal
 |  |  |  |  |  | Major Dia |  | Pitch Dia |  | Minor Dia |  |  | Minor Dia |  | Pitch Dia |  | Major Dia |  | Tap Drill
Size | Size Suffix | Thread Designation | Custom Thread Designation | Pitch | Class | Max | Min | Max | Min | Max | Min | Class | Min | Max | Min | Max | Min | Max | Basic
1.5 |  | 1.5x0.5 | 1.5x0.5 | 0.5 | 6g | 1.520 | 1.380 | 1.215 | 1.110 | 0.910 | 0.840
1.5 |  | ST1.5x0.5 | ST1.5x0.5 | 0.5 | 6g | 1.520 | 1.380 | 1.215 | 1.110 | 0.910 | 0.840
1.9 |  | 1.9x0.6 | 1.9x0.6 | 0.6 | 6g | 1.900 | 1.760 | 1.570 | 1.465 | 1.240 | 1.170
1.9 |  | ST1.9x0.6 | ST1.9x0.6 | 0.6 | 6g | 1.900 | 1.760 | 1.570 | 1.465 | 1.240 | 1.170
2.2 |  | 2.2x0.8 | 2.2x0.8 | 0.8 | 6g | 2.240 | 2.100 | 1.935 | 1.810 | 1.630 | 1.520
2.2 |  | ST2.2x0.8 | ST2.2x0.8 | 0.8 | 6g | 2.240 | 2.100 | 1.935 | 1.810 | 1.630 | 1.520
2.6 |  | 2.6x0.9 | 2.6x0.9 | 0.9 | 6g | 2.570 | 2.430 | 2.235 | 2.115 | 1.900 | 1.800
2.6 |  | ST2.6x0.9 | ST2.6x0.9 | 0.9 | 6g | 2.570 | 2.430 | 2.235 | 2.115 | 1.900 | 1.800
2.9 |  | 2.9x1 | 2.9x1 | 1 | 6g | 2.900 | 2.760 | 2.540 | 2.420 | 2.180 | 2.080
2.9 |  | 2.9x1.1 | 2.9x1.1 | 1.1 | 6g | 2.900 | 2.760 | 2.540 | 2.420 | 2.180 | 2.080
2.9 |  | ST2.9x1.1 | ST2.9x1.1 | 1.1 | 6g | 2.900 | 2.760 | 2.540 | 2.420 | 2.180 | 2.080
2.9 |  | 2.9x1.3 | 2.9x1.3 | 1.3 | 6g | 2.900 | 2.720 | 2.540 | 2.355 | 1.890 | 1.700
2.9 |  | 2.9x1.4 | 2.9x1.4 | 1.4 | 6g | 2.900 | 2.720 | 2.340 | 2.175 | 1.780 | 1.630
3.3 |  | 3.3x1.3 | 3.3x1.3 | 1.3 | 6g | 3.300 | 3.120 | 2.795 | 2.665 | 2.290 | 2.210
3.3 |  | ST3.3x1.3 | ST3.3x1.3 | 1.3 | 6g | 3.300 | 3.120 | 2.795 | 2.665 | 2.290 | 2.210
3.5 |  | 3.5x1.3 | 3.5x1.3 | 1.3 | 6g | 3.530 | 3.350 | 3.085 | 2.930 | 2.640 | 2.510
3.5 |  | ST3.5x1.3 | ST3.5x1.3 | 1.3 | 6g | 3.530 | 3.350 | 3.085 | 2.930 | 2.640 | 2.510
3.5 |  | 3.5x1.6 | 3.5x1.6 | 1.6 | 6g | 3.530 | 3.350 | 2.920 | 2.755 | 2.310 | 2.160
3.5 |  | 3.5x3.2 | 3.5x3.2 | 3.2 | 6g | 3.530 | 3.310 | 2.800 | 2.600 | 2.070 | 1.890
3.9 |  | 3.9x1.3 | 3.9x1.3 | 1.3 | 6g | 3.910 | 3.730 | 3.415 | 3.250 | 2.920 | 2.770
3.9 |  | ST3.9x1.3 | ST3.9x1.3 | 1.3 | 6g | 3.910 | 3.730 | 3.415 | 3.250 | 2.920 | 2.770
3.9 |  | 3.9x1.6 | 3.9x1.6 | 1.6 | 6g | 3.910 | 3.730 | 3.300 | 3.135 | 2.690 | 2.540
3.9 |  | 3.9x3.2 | 3.9x3.2 | 3.2 | 6g | 3.910 | 3.690 | 3.180 | 2.980 | 2.450 | 2.270
4.2 |  | 4.2x1.4 | 4.2x1.4 | 1.4 | 6g | 4.220 | 4.040 | 3.660 | 3.495 | 3.100 | 2.950
4.2 |  | ST4.2x1.4 | ST4.2x1.4 | 1.4 | 6g | 4.220 | 4.040 | 3.660 | 3.495 | 3.100 | 2.950
4.2 |  | 4.2x1.6 | 4.2x1.6 | 1.6 | 6g | 4.220 | 4.040 | 3.610 | 3.445 | 3.000 | 2.850
4.2 |  | 4.2x3.2 | 4.2x3.2 | 3.2 | 6g | 4.220 | 4.000 | 3.380 | 3.180 | 2.540 | 2.360
4.8 |  | 4.8x1.6 | 4.8x1.6 | 1.6 | 6g | 4.800 | 4.620 | 4.190 | 4.025 | 3.580 | 3.430
4.8 |  | ST4.8x1.6 | ST4.8x1.6 | 1.6 | 6g | 4.800 | 4.620 | 4.190 | 4.025 | 3.580 | 3.430
4.8 |  | 4.8x1.8 | 4.8x1.8 | 1.8 | 6g | 4.800 | 4.620 | 4.065 | 3.885 | 3.330 | 3.150
4.8 |  | 4.8x3.2 | 4.8x3.2 | 3.2 | 6g | 4.800 | 4.580 | 3.960 | 3.760 | 3.120 | 2.940
5.5 |  | 5.5x1.8 | 5.5x1.8 | 1.8 | 6g | 5.460 | 5.280 | 4.815 | 4.635 | 4.170 | 3.990
5.5 |  | ST5.5x1.8 | ST5.5x1.8 | 1.8 | 6g | 5.460 | 5.280 | 4.815 | 4.635 | 4.170 | 3.990
6.3 |  | 6.3x1.8 | 6.3x1.8 | 1.8 | 6g | 6.250 | 6.030 | 5.565 | 5.365 | 4.880 | 4.700
6.3 |  | ST6.3x1.8 | ST6.3x1.8 | 1.8 | 6g | 6.250 | 6.030 | 5.565 | 5.365 | 4.880 | 4.700
8.0 |  | 8x2.1 | 8x2.1 | 2.1 | 6g | 8.000 | 7.780 | 7.100 | 6.885 | 6.200 | 5.990
8.0 |  | ST8x2.1 | ST8x2.1 | 2.1 | 6g | 8.000 | 7.780 | 7.100 | 6.885 | 6.200 | 5.990
9.5 |  | 9.5x2.1 | 9.5x2.1 | 2.1 | 6g | 9.650 | 9.430 | 8.750 | 8.510 | 7.850 | 7.590
9.5 |  | ST9.5x2.1 | ST9.5x2.1 | 2.1 | 6g | 9.650 | 9.430 | 8.750 | 8.510 | 7.850 | 7.590

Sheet: ISO Pipe Threads
M Q | ISO-Rohrgewinde |  | Sort Order - 9 |  | External |  |  |  |  |  |  | Internal
 |  |  |  |  |  | Major Dia |  | Pitch Dia |  | Minor Dia |  |  | Minor Dia |  | Pitch Dia |  | Major Dia |  | Tap Drill | Thread Depth | Thread Runouts
Size | Size Suffix | Thread Designation | Custom Thread Designation | TPI | Class | Max | Min | Max | Min | Max | Min | Class | Min | Max | Min | Max | Min | Max | Basic
7.723 |  | G7.723x0.907 | G 1/16 | 28 | A | 7.723 | 7.509 | 7.142 | 7.035 | 6.561 |  |  | 6.561 | 6.834 | 7.142 | 7.249 | 7.723 |  | 1.5875 | 15.446 | 4.5000
7.723 |  | G7.723x0.907 | G 1/16 | 28 | B | 7.723 | 7.509 | 7.142 | 6.928 | 6.561
9.728 |  | G9.728x0.907 | G 1/8 | 28 | A | 9.728 | 9.514 | 9.147 | 9.040 | 8.566 |  |  | 8.566 | 8.848 | 9.147 | 9.254 | 9.728 |  | 3.1750 | 19.456 | 4.5000
9.728 |  | G9.728x0.907 | G 1/8 | 28 | B | 9.728 | 9.514 | 9.147 | 8.933 | 8.566
13.157 |  | G13.157x1.337 | G 1/4 | 19 | A | 13.157 | 12.907 | 12.301 | 12.176 | 11.445 |  |  | 11.445 | 11.89 | 12.301 | 12.426 | 13.157 |  | 6.3500 | 26.314 | 6.5000
13.157 |  | G13.157x1.337 | G 1/4 | 19 | B | 13.157 | 12.907 | 12.301 | 12.051 | 11.445
16.662 |  | G16.662x1.337 | G 3/8 | 19 | A | 16.662 | 16.412 | 15.806 | 15.681 | 14.950 |  |  | 14.95 | 15.395 | 15.806 | 15.931 | 16.662 |  | 9.5250 | 33.324 | 6.5000
16.662 |  | G16.662x1.337 | G 3/8 | 19 | B | 16.662 | 16.412 | 15.806 | 15.556 | 14.950
20.955 |  | G20.955x1.814 | G 1/2 | 14 | A | 20.955 | 20.671 | 19.793 | 19.651 | 18.631 |  |  | 18.631 | 19.172 | 19.793 | 19.935 | 20.955 |  | 12.7000 | 41.910 | 8.5000
20.955 |  | G20.955x1.814 | G 1/2 | 14 | B | 20.955 | 20.671 | 19.793 | 19.509 | 18.631
22.911 |  | G22.911x1.814 | G 5/8 | 14 | A | 22.911 | 22.627 | 21.749 | 21.607 | 20.587 |  |  | 20.587 | 21.128 | 21.749 | 21.891 | 22.911 |  |  | 45.822 | 8.5000
22.911 |  | G22.911x1.814 | G 5/8 | 14 | B | 22.911 | 22.627 | 21.749 | 21.465 | 20.587
26.441 |  | G26.441x1.814 | G 3/4 | 14 | A | 26.441 | 26.157 | 25.279 | 25.137 | 24.117 |  |  | 24.117 | 24.658 | 25.279 | 25.421 | 26.441 |  | 15.8750 | 52.882 | 8.5000
26.441 |  | G26.441x1.814 | G 3/4 | 14 | B | 26.441 | 26.157 | 25.279 | 24.995 | 24.117
30.201 |  | G30.201x1.814 | G 7/8 | 14 | A | 30.201 | 29.917 | 29.039 | 28.897 | 27.877 |  |  | 27.877 | 28.418 | 29.039 | 29.181 | 30.201 |  | 22.2250 | 60.402 | 8.5000
30.201 |  | G30.201x1.814 | G 7/8 | 14 | B | 30.201 | 29.917 | 29.039 | 28.755 | 27.877
33.249 |  | G33.249x2.309 | G 1 | 11 | A | 33.249 | 32.889 | 31.770 | 31.590 | 30.291 |  |  | 30.291 | 30.931 | 31.77 | 31.95 | 33.249 |  | 25.4000 | 66.498 | 10.0000
33.249 |  | G33.249x2.309 | G 1 | 11 | B | 33.249 | 32.889 | 31.770 | 31.410 | 30.291
37.897 |  | G37.897x2.309 | G 1 1/8 | 11 | A | 37.897 | 37.537 | 36.418 | 36.238 | 34.939 |  |  | 34.939 | 35.579 | 36.418 | 36.598 | 37.897 |  | 28.5750 | 75.794 | 10.0000
37.897 |  | G37.897x2.309 | G 1 1/8 | 11 | B | 37.897 | 37.537 | 36.418 | 36.058 | 34.939
41.910 |  | G41.91x2.309 | G 1 1/4 | 11 | A | 41.910 | 41.550 | 40.431 | 40.251 | 38.952 |  |  | 38.952 | 39.592 | 40.431 | 40.611 | 41.910 |  | 31.7500 | 83.820 | 10.0000
41.910 |  | G41.91x2.309 | G 1 1/4 | 11 | B | 41.910 | 41.550 | 40.431 | 40.071 | 38.952
47.803 |  | G47.803x2.309 | G 1 1/2 | 11 | A | 47.803 | 47.443 | 46.324 | 46.144 | 44.845 |  |  | 44.845 | 45.485 | 46.324 | 46.504 | 47.803 |  | 38.1000 | 95.606 | 10.0000
47.803 |  | G47.803x2.309 | G 1 1/2 | 11 | B | 47.803 | 47.443 | 46.324 | 45.964 | 44.845
53.746 |  | G53.746x2.309 | G 1 3/4 | 11 | A | 53.746 | 53.386 | 52.267 | 52.087 | 50.788 |  |  | 50.788 | 51.428 | 52.267 | 52.447 | 53.746 |  | 44.4500 | 107.492 | 10.0000
53.746 |  | G53.746x2.309 | G 1 3/4 | 11 | B | 53.746 | 53.386 | 52.267 | 51.907 | 50.788
59.614 |  | G59.614x2.309 | G 2 | 11 | A | 59.614 | 59.254 | 58.135 | 57.955 | 56.656 |  |  | 56.656 | 57.296 | 58.135 | 58.315 | 59.614 |  | 50.8000 | 119.228 | 10.0000
59.614 |  | G59.614x2.309 | G 2 | 11 | B | 59.614 | 59.254 | 58.135 | 57.775 | 56.656
65.710 |  | G65.71x2.309 | G 2 1/4 | 11 | A | 65.710 | 65.276 | 64.231 | 64.014 | 62.752 |  |  | 62.752 | 63.392 | 64.231 | 64.448 | 65.710 |  | 57.1500 | 131.420 | 10.0000
65.710 |  | G65.71x2.309 | G 2 1/4 | 11 | B | 65.710 | 65.276 | 64.231 | 63.797 | 62.752
75.184 |  | G75.184x2.309 | G 2 1/2 | 11 | A | 75.184 | 74.750 | 73.705 | 73.488 | 72.226 |  |  | 72.226 | 72.866 | 73.705 | 73.922 | 75.184 |  |  | 150.368 | 10.0000
75.184 |  | G75.184x2.309 | G 2 1/2 | 11 | B | 75.184 | 74.750 | 73.705 | 73.271 | 72.226
81.534 |  | G81.534x2.309 | G 2 3/4 | 11 | A | 81.534 | 81.100 | 80.055 | 79.838 | 78.576 |  |  | 78.576 | 79.216 | 80.055 | 80.272 | 81.534 |  | 69.8500 | 163.068 | 10.0000
81.534 |  | G81.534x2.309 | G 2 3/4 | 11 | B | 81.534 | 81.100 | 80.055 | 79.621 | 78.576
87.884 |  | G87.884x2.309 | G 3 | 11 | A | 87.884 | 87.450 | 86.405 | 86.188 | 84.926 |  |  | 84.926 | 85.566 | 86.405 | 86.622 | 87.884 |  | 76.2000 | 175.768 | 10.0000
87.884 |  | G87.884x2.309 | G 3 | 11 | B | 87.884 | 87.450 | 86.405 | 85.971 | 84.926
100.330 |  | G100.33x2.309 | G 3 1/2 | 11 | A | 100.330 | 99.896 | 98.851 | 98.634 | 97.372 |  |  | 97.372 | 98.012 | 98.851 | 99.068 | 100.330 |  | 88.9000 | 200.660 | 10.0000
100.330 |  | G100.33x2.309 | G 3 1/2 | 11 | B | 100.330 | 99.896 | 98.851 | 98.417 | 97.372
113.030 |  | G113.03x2.309 | G 4 | 11 | A | 113.030 | 112.596 | 111.551 | 111.334 | 110.072 |  |  | 110.072 | 110.712 | 111.551 | 111.768 | 113.030 |  | 101.6000 | 226.060 | 10.0000
113.030 |  | G113.03x2.309 | G 4 | 11 | B | 113.030 | 112.596 | 111.551 | 111.117 | 110.072
125.730 |  | G125.73x2.309 | G 4 1/2 | 11 | A | 125.730 | 125.296 | 124.251 | 124.034 | 122.772 |  |  | 122.772 | 123.412 | 124.251 | 124.468 | 125.730 |  | 114.3000 | 251.460 | 10.0000
125.730 |  | G125.73x2.309 | G 4 1/2 | 11 | B | 125.730 | 125.296 | 124.251 | 123.817 | 122.772
138.430 |  | G138.43x2.309 | G 5 | 11 | A | 138.430 | 137.996 | 136.951 | 136.734 | 135.472 |  |  | 135.472 | 136.112 | 136.951 | 137.168 | 138.430 |  | 127.0000 | 276.860 | 10.0000
138.430 |  | G138.43x2.309 | G 5 | 11 | B | 138.430 | 137.996 | 136.951 | 136.517 | 135.472
151.130 |  | G151.13x2.309 | G 5 1/2 | 11 | A | 151.130 | 150.696 | 149.651 | 149.434 | 148.172 |  |  | 148.172 | 148.812 | 149.651 | 149.868 | 151.130 |  | 139.7000 | 302.260 | 10.0000
151.130 |  | G151.13x2.309 | G 5 1/2 | 11 | B | 151.130 | 150.696 | 149.651 | 149.217 | 148.172
163.830 |  | G163.83x2.309 | G 6 | 11 | A | 163.830 | 163.396 | 162.351 | 162.134 | 160.872 |  |  | 160.872 | 161.512 | 162.351 | 162.568 | 163.830 |  | 152.4000 | 327.660 | 10.0000
163.830 |  | G163.83x2.309 | G 6 | 11 | B | 163.830 | 163.396 | 162.351 | 161.917 | 160.872

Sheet: JIS Pipe Threads
M Q | JIS-Rohrgewinde |  | Sort Order -12 |  | External |  |  |  |  |  |  | Internal
 |  |  |  |  |  | Major Dia |  | Pitch Dia |  | Minor Dia |  |  | Minor Dia |  | Pitch Dia |  | Major Dia |  | Tap Drill | Thread Depth | Thread Runouts
Size | Size Suffix | Thread Designation | Custom Thread Designation | TPI | Class | Max | Min | Max | Min | Max | Min | Class | Min | Max | Min | Max | Min | Max | Basic |  | Basic
7.723 |  | G7.723x0.907 | G 1/16 | 28 | A | 7.723 | 7.509 | 7.142 | 7.035 | 6.561 |  |  | 6.561 | 6.834 | 7.142 | 7.249 | 7.723 |  | 1.5875 | 15.446 | 4.5000
7.723 |  | G7.723x0.907 | G 1/16 | 28 | B | 7.723 | 7.509 | 7.142 | 6.928 | 6.561
9.728 |  | G9.728x0.907 | G 1/8 | 28 | A | 9.728 | 9.514 | 9.147 | 9.040 | 8.566 |  |  | 8.566 | 8.848 | 9.147 | 9.254 | 9.728 |  | 3.1750 | 19.456 | 4.5000
9.728 |  | G9.728x0.907 | G 1/8 | 28 | B | 9.728 | 9.514 | 9.147 | 8.933 | 8.566
13.157 |  | G13.157x1.337 | G 1/4 | 19 | A | 13.157 | 12.907 | 12.301 | 12.176 | 11.445 |  |  | 11.445 | 11.89 | 12.301 | 12.426 | 13.157 |  | 6.3500 | 26.314 | 6.5000
13.157 |  | G13.157x1.337 | G 1/4 | 19 | B | 13.157 | 12.907 | 12.301 | 12.051 | 11.445
16.662 |  | G16.662x1.337 | G 3/8 | 19 | A | 16.662 | 16.412 | 15.806 | 15.681 | 14.950 |  |  | 14.95 | 15.395 | 15.806 | 15.931 | 16.662 |  | 9.5250 | 33.324 | 6.5000
16.662 |  | G16.662x1.337 | G 3/8 | 19 | B | 16.662 | 16.412 | 15.806 | 15.556 | 14.950
20.955 |  | G20.955x1.814 | G 1/2 | 14 | A | 20.955 | 20.671 | 19.793 | 19.651 | 18.631 |  |  | 18.631 | 19.172 | 19.793 | 19.935 | 20.955 |  | 12.7000 | 41.910 | 8.5000
20.955 |  | G20.955x1.814 | G 1/2 | 14 | B | 20.955 | 20.671 | 19.793 | 19.509 | 18.631
22.911 |  | G22.911x1.814 | G 5/8 | 14 | A | 22.911 | 22.627 | 21.749 | 21.607 | 20.587 |  |  | 20.587 | 21.128 | 21.749 | 21.891 | 22.911 |  |  | 45.822 | 8.5000
22.911 |  | G22.911x1.814 | G 5/8 | 14 | B | 22.911 | 22.627 | 21.749 | 21.465 | 20.587
26.441 |  | G26.441x1.814 | G 3/4 | 14 | A | 26.441 | 26.157 | 25.279 | 25.137 | 24.117 |  |  | 24.117 | 24.658 | 25.279 | 25.421 | 26.441 |  | 15.8750 | 52.882 | 8.5000
26.441 |  | G26.441x1.814 | G 3/4 | 14 | B | 26.441 | 26.157 | 25.279 | 24.995 | 24.117
30.201 |  | G30.201x1.814 | G 7/8 | 14 | A | 30.201 | 29.917 | 29.039 | 28.897 | 27.877 |  |  | 27.877 | 28.418 | 29.039 | 29.181 | 30.201 |  | 22.2250 | 60.402 | 8.8000
30.201 |  | G30.201x1.814 | G 7/8 | 14 | B | 30.201 | 29.917 | 29.039 | 28.755 | 27.877
33.249 |  | G33.249x2.309 | G 1 | 11 | A | 33.249 | 32.889 | 31.770 | 31.590 | 30.291 |  |  | 30.291 | 30.931 | 31.77 | 31.95 | 33.249 |  | 25.4000 | 66.498 | 10.0000
33.249 |  | G33.249x2.309 | G 1 | 11 | B | 33.249 | 32.889 | 31.770 | 31.410 | 30.291
37.897 |  | G37.897x2.309 | G 1 1/8 | 11 | A | 37.897 | 37.537 | 36.418 | 36.238 | 34.939 |  |  | 34.939 | 35.579 | 36.418 | 36.598 | 37.897 |  | 28.5750 | 75.794 | 10.0000
37.897 |  | G37.897x2.309 | G 1 1/8 | 11 | B | 37.897 | 37.537 | 36.418 | 36.058 | 34.939
41.910 |  | G41.91x2.309 | G 1 1/4 | 11 | A | 41.910 | 41.550 | 40.431 | 40.251 | 38.952 |  |  | 38.952 | 39.592 | 40.431 | 40.611 | 41.910 |  | 31.7500 | 83.820 | 10.0000
41.910 |  | G41.91x2.309 | G 1 1/4 | 11 | B | 41.910 | 41.550 | 40.431 | 40.071 | 38.952
47.803 |  | G47.803x2.309 | G 1 1/2 | 11 | A | 47.803 | 47.443 | 46.324 | 46.144 | 44.845 |  |  | 44.845 | 45.485 | 46.324 | 46.504 | 47.803 |  | 38.1000 | 95.606 | 10.0000
47.803 |  | G47.803x2.309 | G 1 1/2 | 11 | B | 47.803 | 47.443 | 46.324 | 45.964 | 44.845
53.746 |  | G53.746x2.309 | G 1 3/4 | 11 | A | 53.746 | 53.386 | 52.267 | 52.087 | 50.788 |  |  | 50.788 | 51.428 | 52.267 | 52.447 | 53.746 |  | 44.4500 | 107.492 | 10.0000
53.746 |  | G53.746x2.309 | G 1 3/4 | 11 | B | 53.746 | 53.386 | 52.267 | 51.907 | 50.788
59.614 |  | G59.614x2.309 | G 2 | 11 | A | 59.614 | 59.254 | 58.135 | 57.955 | 56.656 |  |  | 56.656 | 57.296 | 58.135 | 58.315 | 59.614 |  | 50.8000 | 119.228 | 10.0000
59.614 |  | G59.614x2.309 | G 2 | 11 | B | 59.614 | 59.254 | 58.135 | 57.775 | 56.656
65.710 |  | G65.71x2.309 | G 2 1/4 | 11 | A | 65.710 | 65.276 | 64.231 | 64.014 | 62.752 |  |  | 62.752 | 63.392 | 64.231 | 64.448 | 65.710 |  | 57.1500 | 131.420 | 10.0000
65.710 |  | G65.71x2.309 | G 2 1/4 | 11 | B | 65.710 | 65.276 | 64.231 | 63.797 | 62.752
75.184 |  | G75.184x2.309 | G 2 1/2 | 11 | A | 75.184 | 74.750 | 73.705 | 73.488 | 72.226 |  |  | 72.226 | 72.866 | 73.705 | 73.922 | 75.184 |  |  | 150.368 | 10.0000
75.184 |  | G75.184x2.309 | G 2 1/2 | 11 | B | 75.184 | 74.750 | 73.705 | 73.271 | 72.226
81.534 |  | G81.534x2.309 | G 2 3/4 | 11 | A | 81.534 | 81.100 | 80.055 | 79.838 | 78.576 |  |  | 78.576 | 79.216 | 80.055 | 80.272 | 81.534 |  | 69.8500 | 163.068 | 10.0000
81.534 |  | G81.534x2.309 | G 2 3/4 | 11 | B | 81.534 | 81.100 | 80.055 | 79.621 | 78.576
87.884 |  | G87.884x2.309 | G 3 | 11 | A | 87.884 | 87.450 | 86.405 | 86.188 | 84.926 |  |  | 84.926 | 85.566 | 86.405 | 86.622 | 87.884 |  | 76.2000 | 175.768 | 10.0000
87.884 |  | G87.884x2.309 | G 3 | 11 | B | 87.884 | 87.450 | 86.405 | 85.971 | 84.926
100.330 |  | G100.33x2.309 | G 3 1/2 | 11 | A | 100.330 | 99.896 | 98.851 | 98.634 | 97.372 |  |  | 97.372 | 98.012 | 98.851 | 99.068 | 100.330 |  | 88.9000 | 200.660 | 10.0000
100.330 |  | G100.33x2.309 | G 3 1/2 | 11 | B | 100.330 | 99.896 | 98.851 | 98.417 | 97.372
113.030 |  | G113.03x2.309 | G 4 | 11 | A | 113.030 | 112.596 | 111.551 | 111.334 | 110.072 |  |  | 110.072 | 110.712 | 111.551 | 111.768 | 113.030 |  | 101.6000 | 226.060 | 10.0000
113.030 |  | G113.03x2.309 | G 4 | 11 | B | 113.030 | 112.596 | 111.551 | 111.117 | 110.072
125.730 |  | G125.73x2.309 | G 4 1/2 | 11 | A | 125.730 | 125.296 | 124.251 | 124.034 | 122.772 |  |  | 122.772 | 123.412 | 124.251 | 124.468 | 125.730 |  | 114.3000 | 251.460 | 10.0000
125.730 |  | G125.73x2.309 | G 4 1/2 | 11 | B | 125.730 | 125.296 | 124.251 | 123.817 | 122.772
138.430 |  | G138.43x2.309 | G 5 | 11 | A | 138.430 | 137.996 | 136.951 | 136.734 | 135.472 |  |  | 135.472 | 136.112 | 136.951 | 137.168 | 138.430 |  | 127.0000 | 276.860 | 10.0000
138.430 |  | G138.43x2.309 | G 5 | 11 | B | 138.430 | 137.996 | 136.951 | 136.517 | 135.472
151.130 |  | G151.13x2.309 | G 5 1/2 | 11 | A | 151.130 | 150.696 | 149.651 | 149.434 | 148.172 |  |  | 148.172 | 148.812 | 149.651 | 149.868 | 151.130 |  | 139.7000 | 302.260 | 10.0000
151.130 |  | G151.13x2.309 | G 5 1/2 | 11 | B | 151.130 | 150.696 | 149.651 | 149.217 | 148.172
163.830 |  | G163.83x2.309 | G 6 | 11 | A | 163.830 | 163.396 | 162.351 | 162.134 | 160.872 |  |  | 160.872 | 161.512 | 162.351 | 162.568 | 163.830 |  | 152.4000 | 327.660 | 10.0000
163.830 |  | G163.83x2.309 | G 6 | 11 | B | 163.830 | 163.396 | 162.351 | 161.917 | 160.872

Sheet: DIN Pipe Threads
M Q | DIN-Rohrgewinde |  | Sort Order - 18 |  | External |  |  |  |  |  |  | Internal
 |  |  |  |  |  | Major Dia |  | Pitch Dia |  | Minor Dia |  |  | Minor Dia |  | Pitch Dia |  | Major Dia |  | Tap Drill | Thread Depth | Thread Runouts
Size | Size Suffix | Thread Designation | Custom Thread Designation | TPI | Class | Max | Min | Max | Min | Max | Min | Class | Min | Max | Min | Max | Min | Max | Basic
7.723 |  | G7.723x0.907 | G 1/16 | 28 | A | 7.723 | 7.509 | 7.142 | 7.035 | 6.561 |  |  | 6.561 | 6.834 | 7.142 | 7.249 | 7.723 |  | 1.5875 | 15.446 | 4.5000
7.723 |  | G7.723x0.907 | G 1/16 | 28 | B | 7.723 | 7.509 | 7.142 | 6.928 | 6.561
9.728 |  | G9.728x0.907 | G 1/8 | 28 | A | 9.728 | 9.514 | 9.147 | 9.040 | 8.566 |  |  | 8.566 | 8.848 | 9.147 | 9.254 | 9.728 |  | 3.1750 | 19.456 | 4.5000
9.728 |  | G9.728x0.907 | G 1/8 | 28 | B | 9.728 | 9.514 | 9.147 | 8.933 | 8.566
13.157 |  | G13.157x1.337 | G 1/4 | 19 | A | 13.157 | 12.907 | 12.301 | 12.176 | 11.445 |  |  | 11.445 | 11.89 | 12.301 | 12.426 | 13.157 |  | 6.3500 | 26.314 | 6.5000
13.157 |  | G13.157x1.337 | G 1/4 | 19 | B | 13.157 | 12.907 | 12.301 | 12.051 | 11.445
16.662 |  | G16.662x1.337 | G 3/8 | 19 | A | 16.662 | 16.412 | 15.806 | 15.681 | 14.950 |  |  | 14.95 | 15.395 | 15.806 | 15.931 | 16.662 |  | 9.5250 | 33.324 | 6.5000
16.662 |  | G16.662x1.337 | G 3/8 | 19 | B | 16.662 | 16.412 | 15.806 | 15.556 | 14.950
20.955 |  | G20.955x1.814 | G 1/2 | 14 | A | 20.955 | 20.671 | 19.793 | 19.651 | 18.631 |  |  | 18.631 | 19.172 | 19.793 | 19.935 | 20.955 |  | 12.7000 | 41.910 | 8.5000
20.955 |  | G20.955x1.814 | G 1/2 | 14 | B | 20.955 | 20.671 | 19.793 | 19.509 | 18.631
22.911 |  | G22.911x1.814 | G 5/8 | 14 | A | 22.911 | 22.627 | 21.749 | 21.607 | 20.587 |  |  | 20.587 | 21.128 | 21.749 | 21.891 | 22.911 |  |  | 45.822 | 8.5000
22.911 |  | G22.911x1.814 | G 5/8 | 14 | B | 22.911 | 22.627 | 21.749 | 21.465 | 20.587
26.441 |  | G26.441x1.814 | G 3/4 | 14 | A | 26.441 | 26.157 | 25.279 | 25.137 | 24.117 |  |  | 24.117 | 24.658 | 25.279 | 25.421 | 26.441 |  | 15.8750 | 52.882 | 8.5000
26.441 |  | G26.441x1.814 | G 3/4 | 14 | B | 26.441 | 26.157 | 25.279 | 24.995 | 24.117
30.201 |  | G30.201x1.814 | G 7/8 | 14 | A | 30.201 | 29.917 | 29.039 | 28.897 | 27.877 |  |  | 27.877 | 28.418 | 29.039 | 29.181 | 30.201 |  | 22.2250 | 60.402 | 8.5000
30.201 |  | G30.201x1.814 | G 7/8 | 14 | B | 30.201 | 29.917 | 29.039 | 28.755 | 27.877
33.249 |  | G33.249x2.309 | G 1 | 11 | A | 33.249 | 32.889 | 31.770 | 31.590 | 30.291 |  |  | 30.291 | 30.931 | 31.77 | 31.95 | 33.249 |  | 25.4000 | 66.498 | 10.5000
33.249 |  | G33.249x2.309 | G 1 | 11 | B | 33.249 | 32.889 | 31.770 | 31.410 | 30.291
37.897 |  | G37.897x2.309 | G 1 1/8 | 11 | A | 37.897 | 37.537 | 36.418 | 36.238 | 34.939 |  |  | 34.939 | 35.579 | 36.418 | 36.598 | 37.897 |  | 28.5750 | 75.794 | 10.5000
37.897 |  | G37.897x2.309 | G 1 1/8 | 11 | B | 37.897 | 37.537 | 36.418 | 36.058 | 34.939
41.910 |  | G41.91x2.309 | G 1 1/4 | 11 | A | 41.910 | 41.550 | 40.431 | 40.251 | 38.952 |  |  | 38.952 | 39.592 | 40.431 | 40.611 | 41.910 |  | 31.7500 | 83.820 | 10.5000
41.910 |  | G41.91x2.309 | G 1 1/4 | 11 | B | 41.910 | 41.550 | 40.431 | 40.071 | 38.952
47.803 |  | G47.803x2.309 | G 1 1/2 | 11 | A | 47.803 | 47.443 | 46.324 | 46.144 | 44.845 |  |  | 44.845 | 45.485 | 46.324 | 46.504 | 47.803 |  | 38.1000 | 95.606 | 10.5000
47.803 |  | G47.803x2.309 | G 1 1/2 | 11 | B | 47.803 | 47.443 | 46.324 | 45.964 | 44.845
53.746 |  | G53.746x2.309 | G 1 3/4 | 11 | A | 53.746 | 53.386 | 52.267 | 52.087 | 50.788 |  |  | 50.788 | 51.428 | 52.267 | 52.447 | 53.746 |  | 44.4500 | 107.492 | 10.5000
53.746 |  | G53.746x2.309 | G 1 3/4 | 11 | B | 53.746 | 53.386 | 52.267 | 51.907 | 50.788
59.614 |  | G59.614x2.309 | G 2 | 11 | A | 59.614 | 59.254 | 58.135 | 57.955 | 56.656 |  |  | 56.656 | 57.296 | 58.135 | 58.315 | 59.614 |  | 50.8000 | 119.228 | 10.5000
59.614 |  | G59.614x2.309 | G 2 | 11 | B | 59.614 | 59.254 | 58.135 | 57.775 | 56.656
65.710 |  | G65.71x2.309 | G 2 1/4 | 11 | A | 65.710 | 65.276 | 64.231 | 64.014 | 62.752 |  |  | 62.752 | 63.392 | 64.231 | 64.448 | 65.710 |  | 57.1500 | 131.420 | 10.5000
65.710 |  | G65.71x2.309 | G 2 1/4 | 11 | B | 65.710 | 65.276 | 64.231 | 63.797 | 62.752
75.184 |  | G75.184x2.309 | G 2 1/2 | 11 | A | 75.184 | 74.750 | 73.705 | 73.488 | 72.226 |  |  | 72.226 | 72.866 | 73.705 | 73.922 | 75.184 |  |  | 150.368 | 10.5000
75.184 |  | G75.184x2.309 | G 2 1/2 | 11 | B | 75.184 | 74.750 | 73.705 | 73.271 | 72.226
81.534 |  | G81.534x2.309 | G 2 3/4 | 11 | A | 81.534 | 81.100 | 80.055 | 79.838 | 78.576 |  |  | 78.576 | 79.216 | 80.055 | 80.272 | 81.534 |  | 69.8500 | 163.068 | 10.5000
81.534 |  | G81.534x2.309 | G 2 3/4 | 11 | B | 81.534 | 81.100 | 80.055 | 79.621 | 78.576
87.884 |  | G87.884x2.309 | G 3 | 11 | A | 87.884 | 87.450 | 86.405 | 86.188 | 84.926 |  |  | 84.926 | 85.566 | 86.405 | 86.622 | 87.884 |  | 76.2000 | 175.768 | 10.5000
87.884 |  | G87.884x2.309 | G 3 | 11 | B | 87.884 | 87.450 | 86.405 | 85.971 | 84.926
100.330 |  | G100.33x2.309 | G 3 1/2 | 11 | A | 100.330 | 99.896 | 98.851 | 98.634 | 97.372 |  |  | 97.372 | 98.012 | 98.851 | 99.068 | 100.330 |  | 88.9000 | 200.660 | 10.5000
100.330 |  | G100.33x2.309 | G 3 1/2 | 11 | B | 100.330 | 99.896 | 98.851 | 98.417 | 97.372
113.030 |  | G113.03x2.309 | G 4 | 11 | A | 113.030 | 112.596 | 111.551 | 111.334 | 110.072 |  |  | 110.072 | 110.712 | 111.551 | 111.768 | 113.030 |  | 101.6000 | 226.060 | 10.5000
113.030 |  | G113.03x2.309 | G 4 | 11 | B | 113.030 | 112.596 | 111.551 | 111.117 | 110.072
125.730 |  | G125.73x2.309 | G 4 1/2 | 11 | A | 125.730 | 125.296 | 124.251 | 124.034 | 122.772 |  |  | 122.772 | 123.412 | 124.251 | 124.468 | 125.730 |  | 114.3000 | 251.460 | 10.5000
125.730 |  | G125.73x2.309 | G 4 1/2 | 11 | B | 125.730 | 125.296 | 124.251 | 123.817 | 122.772
138.430 |  | G138.43x2.309 | G 5 | 11 | A | 138.430 | 137.996 | 136.951 | 136.734 | 135.472 |  |  | 135.472 | 136.112 | 136.951 | 137.168 | 138.430 |  | 127.0000 | 276.860 | 10.5000
138.430 |  | G138.43x2.309 | G 5 | 11 | B | 138.430 | 137.996 | 136.951 | 136.517 | 135.472
151.130 |  | G151.13x2.309 | G 5 1/2 | 11 | A | 151.130 | 150.696 | 149.651 | 149.434 | 148.172 |  |  | 148.172 | 148.812 | 149.651 | 149.868 | 151.130 |  | 139.7000 | 302.260 | 10.5000
151.130 |  | G151.13x2.309 | G 5 1/2 | 11 | B | 151.130 | 150.696 | 149.651 | 149.217 | 148.172
163.830 |  | G163.83x2.309 | G 6 | 11 | A | 163.830 | 163.396 | 162.351 | 162.134 | 160.872 |  |  | 160.872 | 161.512 | 162.351 | 162.568 | 163.830 |  | 152.4000 | 327.660 | 10.5000
163.830 |  | G163.83x2.309 | G 6 | 11 | B | 163.830 | 163.396 | 162.351 | 161.917 | 160.872

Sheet: BSP Pipe Threads
M Q | BSP-Rohrgewinde |  | Sort Order - 19 |  | External |  |  |  |  |  |  | Internal
 |  |  |  |  |  | Major Dia |  | Pitch Dia |  | Minor Dia |  |  | Minor Dia |  | Pitch Dia |  | Major Dia |  | Tap Drill | Thread Depth | Thread Runouts
Size | Size Suffix | Thread Designation | Custom Thread Designation | TPI | Class | Max | Min | Max | Min | Max | Min | Class | Min | Max | Min | Max | Min | Max | Basic |  | Basic
1/16 |  | G 1/16-28 | G 1/16-28 | 28 | A | 7.723 | 7.509 | 7.142 | 7.035 | 6.561 |  |  | 6.561 | 6.834 | 7.142 | 7.249 | 7.723 |  | 6.6000 | 15.4460 | 4.5000
1/16 |  | G 1/16-28 | G 1/16-28 | 28 | B | 7.723 | 7.509 | 7.142 | 7.035 | 6.561
1/8 |  | G 1/8-28 | G 1/8-28 | 28 | A | 9.728 | 9.514 | 9.147 | 9.040 | 8.566 |  |  | 8.566 | 8.848 | 9.147 | 9.254 | 9.728 |  | 8.7300 | 19.4560 | 4.5000
1/8 |  | G 1/8-28 | G 1/8-28 | 28 | B | 9.728 | 9.514 | 9.147 | 9.040 | 8.566
1/4 |  | G 1/4-19 | G 1/4-19 | 19 | A | 13.157 | 12.907 | 12.301 | 12.176 | 11.445 |  |  | 11.445 | 11.89 | 12.301 | 12.426 | 13.157 |  | 11.8000 | 26.3140 | 6.5000
1/4 |  | G 1/4-19 | G 1/4-19 | 19 | B | 13.157 | 12.907 | 12.301 | 12.176 | 11.445
3/8 |  | G 3/8-19 | G 3/8-19 | 19 | A | 16.662 | 16.412 | 15.806 | 15.681 | 14.950 |  |  | 14.95 | 15.395 | 15.806 | 15.931 | 16.662 |  | 15.2500 | 33.3240 | 6.5000
3/8 |  | G 3/8-19 | G 3/8-19 | 19 | B | 16.662 | 16.412 | 15.806 | 15.681 | 14.950
1/2 |  | G 1/2-14 | G 1/2-14 | 14 | A | 20.955 | 20.671 | 19.793 | 19.651 | 18.631 |  |  | 18.631 | 19.172 | 19.793 | 19.935 | 20.955 |  | 19.0500 | 41.9100 | 8.5000
1/2 |  | G 1/2-14 | G 1/2-14 | 14 | B | 20.955 | 20.671 | 19.793 | 19.651 | 18.631
5/8 |  | G 5/8-14 | G 5/8-14 | 14 | A | 22.911 | 22.627 | 21.749 | 21.607 | 20.587 |  |  | 20.587 | 21.128 | 21.749 | 21.891 | 22.911 |  | 21.0000 | 45.8220 | 8.5000
5/8 |  | G 5/8-14 | G 5/8-14 | 14 | B | 22.911 | 22.627 | 21.749 | 21.607 | 20.587
3/4 |  | G 3/4-14 | G 3/4-14 | 14 | A | 26.441 | 26.157 | 25.279 | 25.137 | 24.117 |  |  | 24.117 | 24.658 | 25.279 | 25.421 | 26.441 |  | 24.5000 | 52.8820 | 8.5000
3/4 |  | G 3/4-14 | G 3/4-14 | 14 | B | 26.441 | 26.157 | 25.279 | 25.137 | 24.117
7/8 |  | G 7/8-14 | G 7/8-14 | 14 | A | 30.201 | 29.917 | 29.039 | 28.897 | 27.877 |  |  | 27.877 | 28.418 | 29.039 | 29.181 | 30.201 |  | 28.2500 | 60.4020 | 8.5000
7/8 |  | G 7/8-14 | G 7/8-14 | 14 | B | 30.201 | 29.917 | 29.039 | 28.897 | 27.877
1 |  | G 1-11 | G 1-11 | 11 | A | 33.249 | 32.889 | 31.770 | 31.590 | 30.291 |  |  | 30.291 | 30.931 | 31.77 | 31.95 | 33.249 |  | 30.7500 | 66.4980 | 10.0000
1 |  | G 1-11 | G 1-11 | 11 | B | 33.249 | 32.889 | 31.770 | 31.590 | 30.291
1 1/4 |  | G 1 1/4-11 | G 1 1/4-11 | 11 | A | 41.910 | 41.550 | 40.431 | 40.251 | 38.952 |  |  | 38.952 | 39.592 | 40.431 | 40.611 | 41.910 |  | 39.5000 | 83.8200 | 10.0000
1 1/4 |  | G 1 1/4-11 | G 1 1/4-11 | 11 | B | 41.910 | 41.550 | 40.431 | 40.251 | 38.952
1 1/2 |  | G 1 1/2-11 | G 1 1/2-11 | 11 | A | 47.803 | 47.443 | 46.324 | 46.144 | 44.845 |  |  | 44.845 | 45.485 | 46.324 | 46.504 | 47.803 |  | 45.5000 | 95.6060 | 10.0000
1 1/2 |  | G 1 1/2-11 | G 1 1/2-11 | 11 | B | 47.803 | 47.443 | 46.324 | 46.144 | 44.845
1 3/4 |  | G 1 3/4-11 | G 1 3/4-11 | 11 | A | 53.746 | 53.386 | 52.267 | 52.087 | 50.788 |  |  | 50.788 | 51.428 | 52.267 | 52.447 | 53.746 |  | 51.0000 | 107.4920 | 10.0000
1 3/4 |  | G 1 3/4-11 | G 1 3/4-11 | 11 | B | 53.746 | 53.386 | 52.267 | 52.087 | 50.788
2 |  | G 2-11 | G 2-11 | 11 | A | 59.614 | 59.254 | 58.135 | 57.955 | 56.656 |  |  | 56.656 | 57.296 | 58.135 | 58.315 | 59.614 |  | 57.0000 | 119.2280 | 10.0000
2 |  | G 2-11 | G 2-11 | 11 | B | 59.614 | 59.254 | 58.135 | 57.955 | 56.656
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

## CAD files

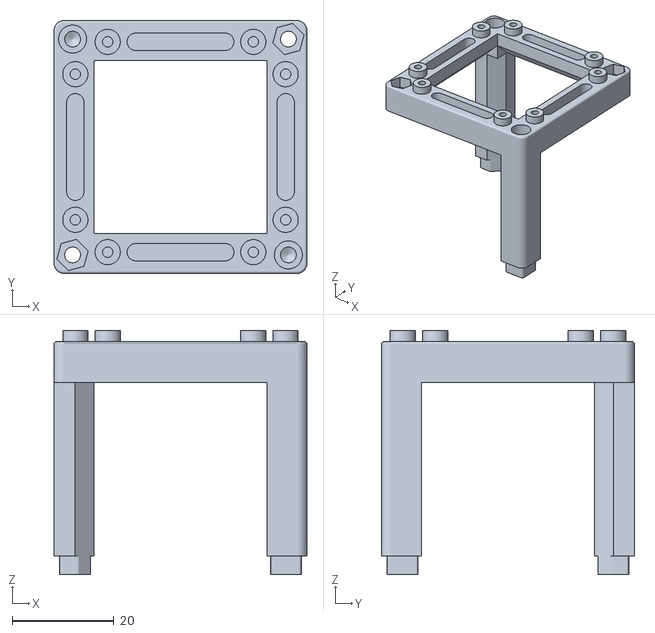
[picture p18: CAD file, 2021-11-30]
STL/APP_UC2_STORM__10_Cube_1x1_IM_120.stl
49.7 x 49.7 x 48.0

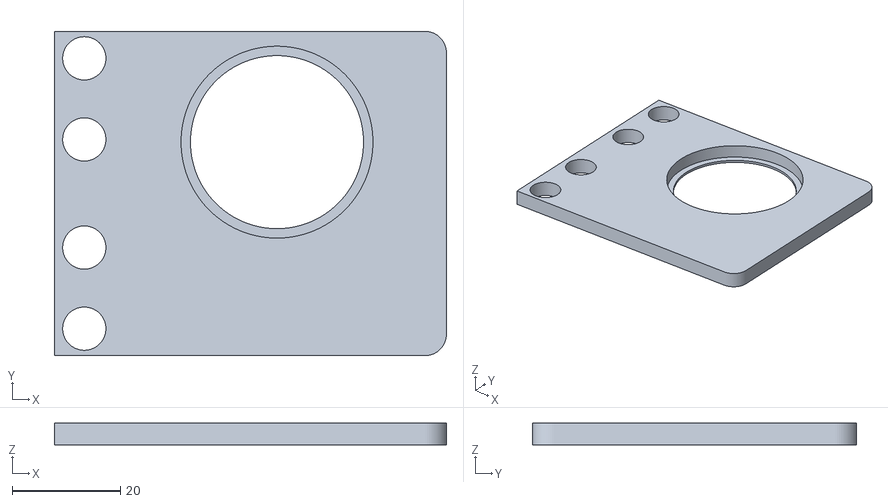
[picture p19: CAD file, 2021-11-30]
STL/APP_UC2_STORM__30_cellSTORM_XY_Sample_arm_35mmadapter_49.stl
72.5 x 60.0 x 4.00

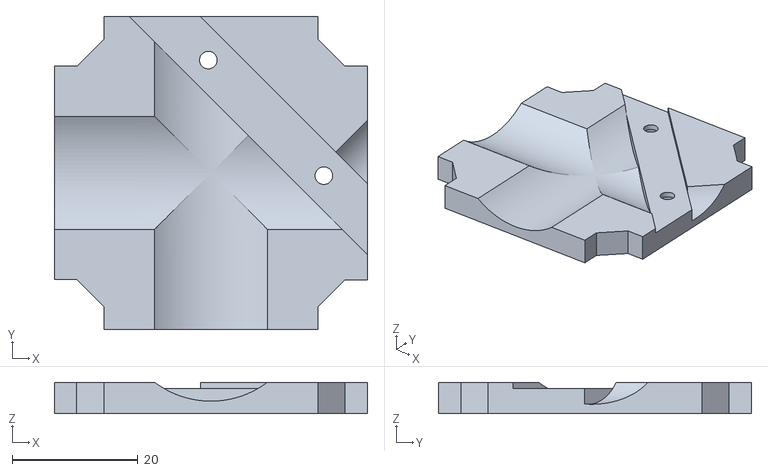
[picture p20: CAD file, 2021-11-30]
STL/APP_UC2_STORM__20_Cube_Insert_Kinematic_Mirrormount_45_base_part1_88.stl
49.8 x 49.8 x 5.00

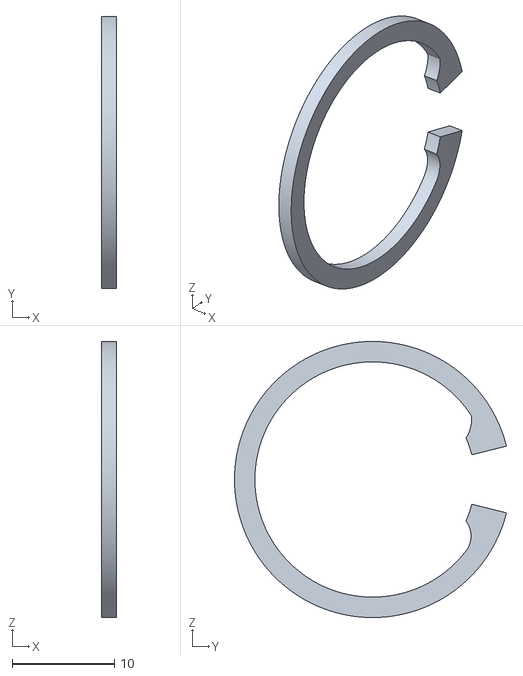
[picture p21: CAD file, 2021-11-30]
STL/APP_UC2_STORM__20_Cube_Insert_Beamsplittercube_Retainring_25mm_83.stl
1.50 x 26.6 x 27.0

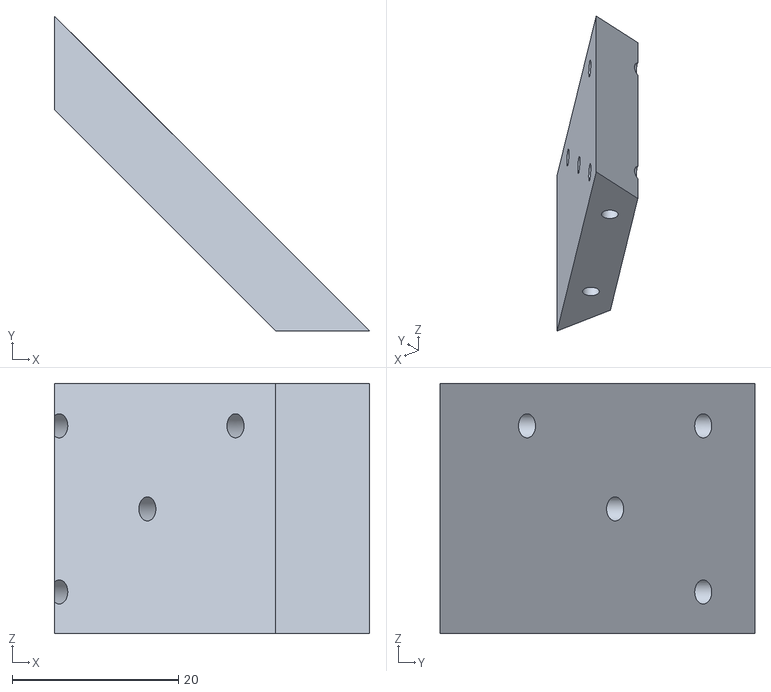
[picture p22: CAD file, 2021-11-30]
STL/APP_UC2_STORM__20_Cube_Insert_Kinematic_Mirrormount_45_base_part2_20.stl
37.9 x 37.9 x 30.1

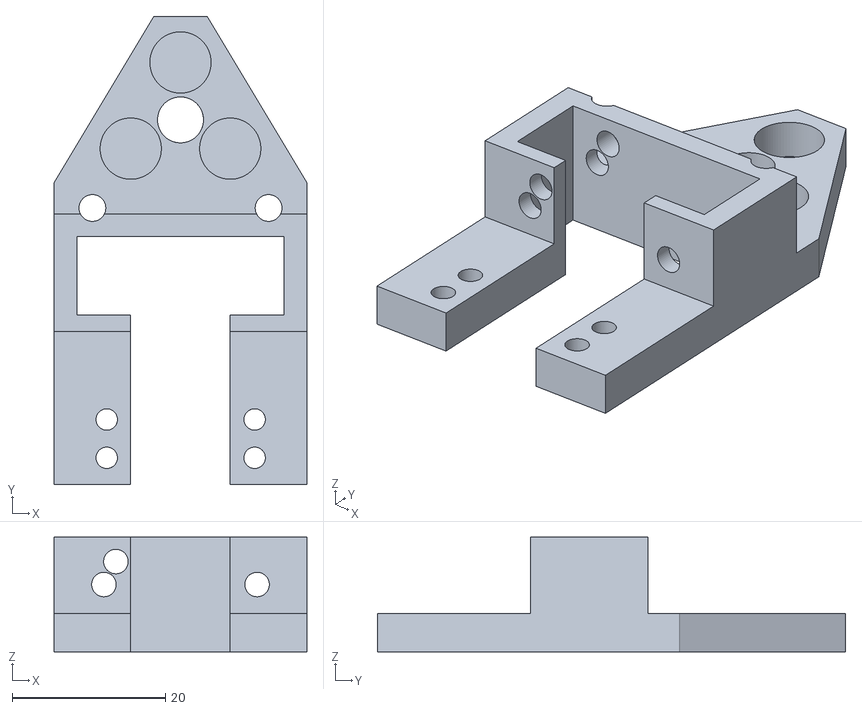
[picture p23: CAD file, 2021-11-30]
STL/APP_UC2_STORM__30_Cube_Z_Focus_MGN12_NEMA_slide_part2_106.stl
33.0 x 61.1 x 15.0

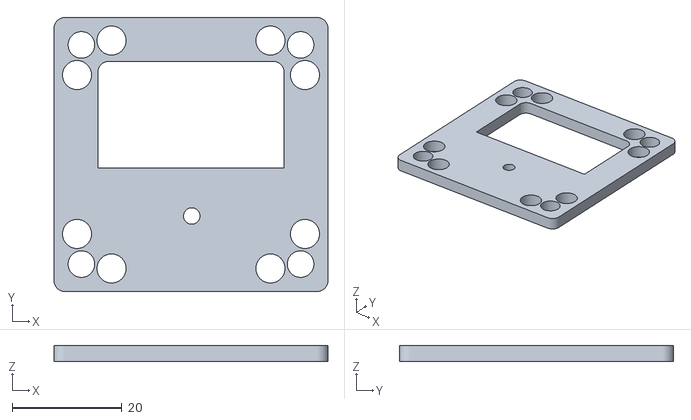
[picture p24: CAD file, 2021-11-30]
STL/APP_UC2_STORM__30_Cube_Z_Focus_MGN_NEMA_counterplate_122.stl
50.0 x 50.0 x 3.00

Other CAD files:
INVENTOR/Templates/English/ANSI (in).dwg
INVENTOR/Templates/Metric/JIS.dwg
INVENTOR/Templates/Standard.dwg
INVENTOR/Templates/Metric/BSI.dwg
INVENTOR/Templates/Metric/ISO.dwg
INVENTOR/Templates/Metric/ANSI (mm).dwg
INVENTOR/Templates/Metric/GOST.dwg
INVENTOR/Templates/Metric/DIN.dwg
STL/APP_UC2_STORM__10_Cube_1x1_IM_127.stl
INVENTOR/Templates/Metric/GB.dwg
STL/APP_UC2_STORM__10_Cube_1x1_IM_118.stl
INVENTOR/00_BallMagnets_5mm_single.ipt
INVENTOR/00_Chroma_Dichroic_25x,3x1.ipt
INVENTOR/00_Comar_Filter_25Dia.ipt
INVENTOR/00_Laser_532nm_200mw.ipt
INVENTOR/00_MGN12H, LINEAR GUIDE BLOCK.ipt
INVENTOR/00_Microscope_Objective.ipt
INVENTOR/00_Motorcoupling_5mm_M3.ipt
INVENTOR/00_NEMA11.ipt
INVENTOR/00_SMLM_chamber.ipt
INVENTOR/00_Stepper_Motor_28BYJ-48.ipt
INVENTOR/00_Thorlabs_PF10-03-P01-Step.ipt
INVENTOR/00_XY_stage-CHUO_SEIKI_LD-647-R1-Bottom.ipt
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

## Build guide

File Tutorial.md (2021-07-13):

# Tutorial:
__________________
*How to use the UC2 infinity-corrected microscope?*

Version: 2020-08-11

This tutorial correpsonds to the Nvidia Jetson GUI in our [Software-Branch](https://github.com/bionanoimaging/UC2-Software-GIT). 

### Connect to the Jetson

The current Jetson Nano runs with Linux (Ubuntu). You can connect to it using ```SSH```. The easiest is to create a WiFi Hotspot with an Android (tested, possibly also iPHONE) cellphone. Connect your computer (e.g. MAC/Windows) as well as the Jetson to it.

#### MAC

- Open the terminal

```
cd /home/bene/Downloads/UC2-Software-GIT/GUI/RASPBERRY_PI/RASPIapp_py3
export DISPLAY=:0
python main.py
```

#### Windows 

- Download and install WinSCP + Putty 
- open Putty and connect to the Nvidia Jetson Nano; Use its IP which can be determined by typing ifconfig into the terminal 

expected output:

```
[INFO   ] [Logger      ] Record log in /home/bene/.kivy/logs/kivy_20-08-11_5.txt
[INFO   ] [Kivy        ] v2.0.0rc3, git-9ff5f12, 20200803
[INFO   ] [Kivy        ] Installed at "/home/bene/.local/lib/python3.7/site-packages/kivy/__init__.py"
[INFO   ] [Python      ] v3.7.5 (default, Nov  7 2019, 10:50:52) 
[GCC 8.3.0]
[INFO   ] [Python      ] Interpreter at "/usr/bin/python3.7"
[INFO   ] [Factory     ] 186 symbols loaded
[INFO   ] [Image       ] Providers: img_tex, img_dds, img_sdl2, img_pil (img_ffpyplayer ignored)
[INFO   ] [Text        ] Provider: sdl2(['text_pango'] ignored)
[INFO   ] [Window      ] Provider: sdl2
dbus[8533]: arguments to dbus_message_new_method_call() were incorrect, assertion "path != NULL" failed in file ../../../dbus/dbus-message.c line 1362.
This is normally a bug in some application using the D-Bus library.

[INFO   ] [GL          ] Using the "OpenGL" graphics system
[INFO   ] [GL          ] Backend used <gl>
[INFO   ] [GL          ] OpenGL version <b'4.6.0 NVIDIA 32.3.1'>
[INFO   ] [GL          ] OpenGL vendor <b'NVIDIA Corporation'>
[INFO   ] [GL          ] OpenGL renderer <b'NVIDIA Tegra X1 (nvgpu)/integrated'>
[INFO   ] [GL          ] OpenGL parsed version: 4, 6
[INFO   ] [GL          ] Shading version <b'4.60 NVIDIA'>
[INFO   ] [GL          ] Texture max size <16384>
[INFO   ] [GL          ] Texture max units <32>
[INFO   ] [Window      ] auto add sdl2 input provider
[INFO   ] [Window      ] virtual keyboard not allowed, single mode, not docked
ERROR: Could not import scipy!
[ DEBUG    ] [ UC2           ] Logging successfully initialized to -> uc2-20200811_122326.log
Configuration file loaded
```

alternative double-click on the icon on the Desktop ```startUC2.sh```. 

## Getting started

### UC2 GUI 

The GUI has the following functionalities:

```
- BURST: Take fluorescent images at "high-speed" (T=0.5s)
- Preview: Observe the image using the preview window 
- Long-Term experiments: Take fluorescent and/or brightfield images sequentially (T>1s, multiple days)
- Hardware control: X/Y/Z, Laser intensity, LED on/off
```

*Quick tour:*

<p align="center">

</p> 

#### BURST-Mode *(T<1s)*

You can take fluorescent images at a rate of *0.5 s* by first (!) pressing the button "BURST", then hit "Start Preview". The images will be saved in the Folder ```DATA``` with a unique name which follows the current date. 

#### Long-term Acquisitions *(T>1s)*

For long-term image series where you want to have multi-modal imaging capabilities (e.g. BF+FLUO), you can hit "Start Experiment" and choose the period and length of the experiment. Then select Fluo and/or BF and start the experiment. The images are saved in the folder ```data```. 

#### Hardware Control

##### XYZ-Stage

The deltastage from the openflexure project can be controlled by first typing the direction button (e.g. ***X***) and then drive back/forth. You can vary the step-size by pressing ***--/++***. The stage may wobble, we will update that soon! 

##### Fluorscence (Laser)

The button ***FLUO*** activates the laser which can be controled in intensity. Therefore move the slider until you get the right intensity in the sample plane. 

##### Brightfield 

The button ***FULL*** activates the LED. 

### Vimba Viewer 

You can start the VIMBA-Viewer by double clicking the Icon ```startVimbaViewer.sh```on the Desktop. It starts the GUI to have full control over the camera:

<p align="center">
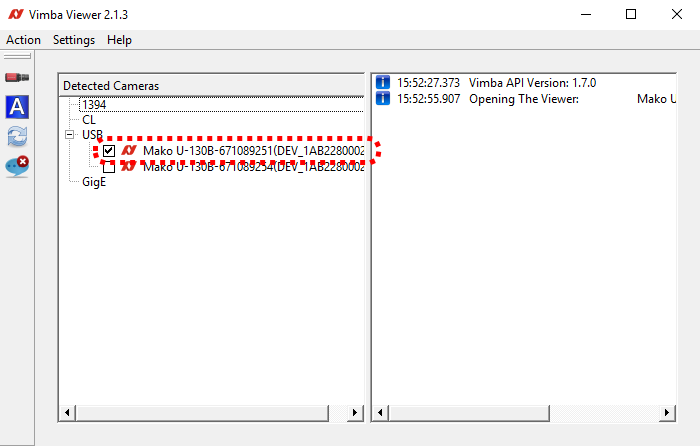
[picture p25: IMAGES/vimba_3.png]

</p> 

## Align the setup

1. Mount the LED with this tripod mechanism so that it's in the center of the Objective lens
2. Follow the path of the transmitted light until . It has to go tr
## Mount the sample 

## Focus the sample 

## Downloading Data

### BURST Data

The data can be found in the folder ```./DATA```

### Long-term Data

The data can be found in the folder ```./data```

## Trouble Shooting
 
### If nothing is woking

-  Did you turn it off and on again?

### Autofocus does not work

- This feature is currently not implemented in the Alvium Camera framework

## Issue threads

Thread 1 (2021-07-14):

Review and update

b286, 2021-07-14:
Please check that the information provided here is correct and if possible update the repository. Thank you ❤️

beniroquai, 2021-07-17:
At one point it surely requires an update. But for now it looks great1 Thanks! :)

renerichter, 2021-08-05:
Links to CAD-designs seem to be broken, eg

- was: https://github.com/openUC2/UC2-GIT/CAD/ASSEMBLY_Baseplate/
- has to be now: https://github.com/openUC2/UC2-GIT/tree/master/CAD/ASSEMBLY_Baseplate

Maybe this is true for many other repos as well?

beniroquai, 2021-08-08:
Solved in #476848b

Closed 2021-08-08.
